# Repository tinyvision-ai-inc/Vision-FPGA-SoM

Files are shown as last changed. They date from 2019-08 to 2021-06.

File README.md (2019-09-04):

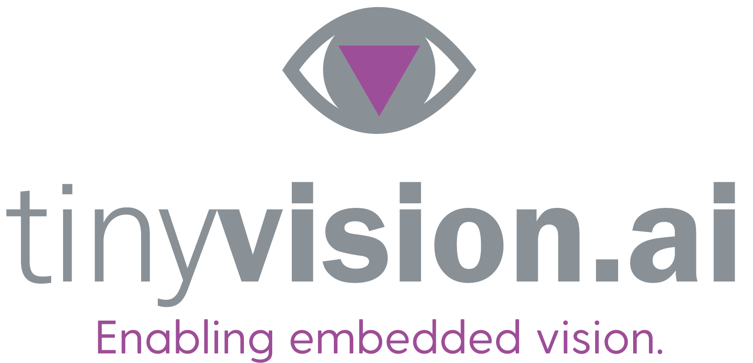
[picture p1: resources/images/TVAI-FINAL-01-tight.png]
tinyVision.ai Inc.

# Vision, Audio &amp; Motion FPGA SoM
## Low Power Sensing/processing System on Module

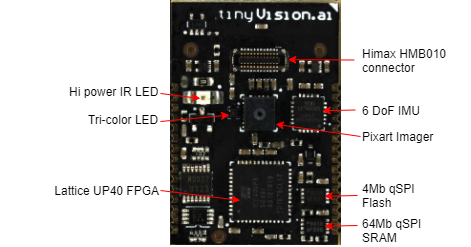
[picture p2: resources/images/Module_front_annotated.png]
Module Front


The Vision, Audio and Motion FPGA SoM enables IoT devices to see, hear and sense motion. This is a tightly integrated platform consisting of a low power image sensor, microphone and 6-DoF IMU coupled to a local computing device ([Lattice ultra low power ICE40 UltraPlus 5K FPGA](http://www.latticesemi.com/en/Products/FPGAandCPLD/iCE40UltraPlus)).

Typical applications of the SoM include image capture, trigger/capture images on motion (vision or IMU based), human face/presence detection, keyphrase detection and gestures.

The SoM is designed to be integrated into devices to enable edge computing, significantly shortening the time to market and allowing the developer to focus on their differentiation.

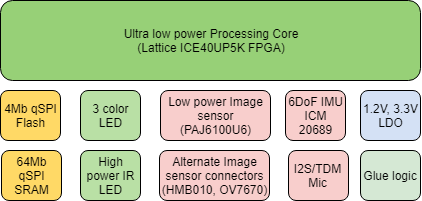
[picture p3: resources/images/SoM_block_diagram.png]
Vision Audio and Motion FPGA SoM Diagram


The module integrates the following capabilities:

- Local processing using the Lattice ICE40 Ultra Plus 5K Ultra-low-power FPGA, 5K LUT, 1Mb RAM, 8 MAC units
- Image sensor options
  - Integrated qVGA monochrome global shutter imager (Pixart PAJ6100U6)
  - Connector for color/monochrome rolling shutter imager (Himax HMB010)
  - Connector for OV7670 flex
- One MEMS I2S/TDM microphone, expandable to up to 8 microphones
- LED's
  - Tri-colour LED
  - IR LED for low light illumination with exposure synchronization
- 6 axis Gyro/accelerometer (Invensense IMU 60289)
- Memory
  - 8Mb qSPI Flash for bitstream/code storage
  - 64Mb qSPI SRAM for data
- Four GPIO, programmable IO voltage
- 4 wire SPI host interface with programmable IO voltage
- 2 power options:
  - Single 3.3V operation, can supply 1.8V and 1.2V @100mA (max) to external devices using onboard LDO
  - External 3.3V, 1.8V, 1.2V for lower power operation
- Supports the Lattice [SensAI](https://www.latticesemi.com/sensAI) toolchain using Tensorflow/Caffe/Keras for model development, quantization and mapping to the SensAI Neural Network engines.
  - Single and 8-bit neural networks
  - Models provided for face and human presence detection, gestures
  - Performance of >30 fps for inferencing at <15 mW
- Small size: 21.3mm x 31.3mm
- [Developer kit](./SoM/SoM_devkit_details.png) enables fast prototyping of complete end applications.

For more details, please see the [Datasheet](resources/som_details/Sensor_FPGA_SoM_data_sheet_2.0.pdf) and [SoM specification](SoM/README.md). A 3-D PDF rendering is available [here](resources/som_details/SoM_3D.pdf).

Modules and developer kits are available at the tinyVision.ai [store](https://tinyvision.ai/). Please contact us for questions about the module at: <sales.at.tinyvision.ai> .

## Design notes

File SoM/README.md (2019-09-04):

Module Front
<!img src="../resources/images/Module_back.jpg" alt="Module Back" width="100"/-->

# SoM Details

- [High level interconnect](../resources/images/SoM_interconnect_details.png)
- [Detailed SoM specification](./SoM_Specification.md).
- [Schematics](./Schematics)
- [Verilog examples](./RTL)
- Sensors
  - [Image sensor data](./Misc/Images)
  - [Microphone data](Misc/Audio)
  - [IMU data](./Misc/IMU)
- [STEP & DXF files](../resources/som_details/)
- [Developer kit details](../resources/images/SoM_devkit_details.png)

## Mechanical
The SoM is designed to be plugged into a connector on the host board or to be soldered down using the castellations to reduce system cost. Note that since the on-board microphone is bottom ported, this requires that the soldered down version not have a microphone which is an alternate part. Please contact us at sales.at.tinyvision.ai if this is of interest.

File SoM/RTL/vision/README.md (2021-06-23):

# High level description
The Vision directory has a basic test application that allows the user to get images from the board.

An image is captured by sending a character on the UART when the devkit is connected. The captured image is then sent back over the UART at the default baud rate of 460,800 baud. Note that this can be changed by changing the UART_PERIOD parameter in the code.

Further details can be found in the sw directory.

## Simulations
The following simulations can be run using Modelsim installed along with the Radiant toolchain. Change to the sim directory and run the following commands:
- `make TOP=<block>`: Compiles the code
- `make TOP=<block> sim`: Runs the simulation in the shell
- `make TOP=<block> sim_gui`: Runs the simulation in a GUI

Simulations are visual and not self checking, an enhancement for another day!

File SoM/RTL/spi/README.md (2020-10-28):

# SPI Slave to Wishbone Master bridge
This block forms the main core interface to the FPGA since all data enters/exits through the SPI. The design follows a simple byte oriented protocol that allows direct Wishbone read/write. Since the FPGA is a SPI slave, a side band interrupt request line is also provided and integrated into the protocol for fast interrupt service.

A SPI packet consists of the first byte containing a command followed by an optional address and either a dummy byte or write data. A dummy byte is required to do a read which takes some time in the FPGA.

The following commands are supported, roughly based on typical Flash commands:
- Read ID ( '0x90' ): A 1 byte FPGA ID will be read back immediately following this command with no dummy byte.
- Read Status ( '0x05' ): A 4 (TBD) byte Status will be read back immediately following this command with no dummy byte. A continued read of the status will show any changes in status in real time. Status words typically include an interrupt request bit.
- Write Command ( '0x01' ): This can be used to clear any sticky bits in the status register such as an interrupt request.
- Read ( '0x0B' ): A 32 bit address followed by a dummy byte then a stream of reads will cause Wishbone read's to happen every 32 bits. This scheme allows for indefinite length Read capability.
- Write ( '0x02' ): A 32 bit address and then a stream of 32 bit data wordxs follows this command. A Wishbone write goes out at every 32 bit boundary. This scheme allows for indefinite length write capability.
- Soft Reset FPGA: The FPGA can be soft reset using a pair of commands that must be sent one after the other with no other intervening commands. This prevent inadvertent FPGA resets.
  - Arm Reset ( '0x66' )
  - Fire Reset ( '0x99' )

## Interrupt Service
Interrupts are supported using a dedicated interrupt line. THis line goes active as soon as the interrupt is requested at the core interface. A STATUS read will show the source of the interrupt. Interrupts are captured on the rising edge of the core clock and can be cleared by writing the respective bit with a '1' in the command word.

## Future work
- Quad SPI support

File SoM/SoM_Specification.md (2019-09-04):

# SoM Specification

The Sensor module uses a Lattice iCE40UP5K QFN device as its core programmable device. This part is connected to and supported by various other components on the board. Please refer to the [schematic](../SoM/Schematics/SoM) of the SoM for details.

The board has an I2S microphone, Invensense IMU and an installed low power low-cost monochrome camera (PAJ6100U6) from Pixart Inc. In addition, provision is made for a Himax HM01B0 low power camera and also an OV7670 Omnivision flex connector. These options allow for various applications. An IR LED is connected to the Pixart sensor to allow for illumination of the scene with the LED synchronized to the shutter.
The FPGA is connected to 4Mb of qSPI capable NOR flash for booting as well as storage of other code. The qSPI bus is shared with a 64Mb qSPI SRAM. The SRAM can be used for buffering sensor or intermediate data such as video frames and/or audio streams. Selection between the flash and SRAM is done using dedicated active-low slave select lines.

## Electrical interface

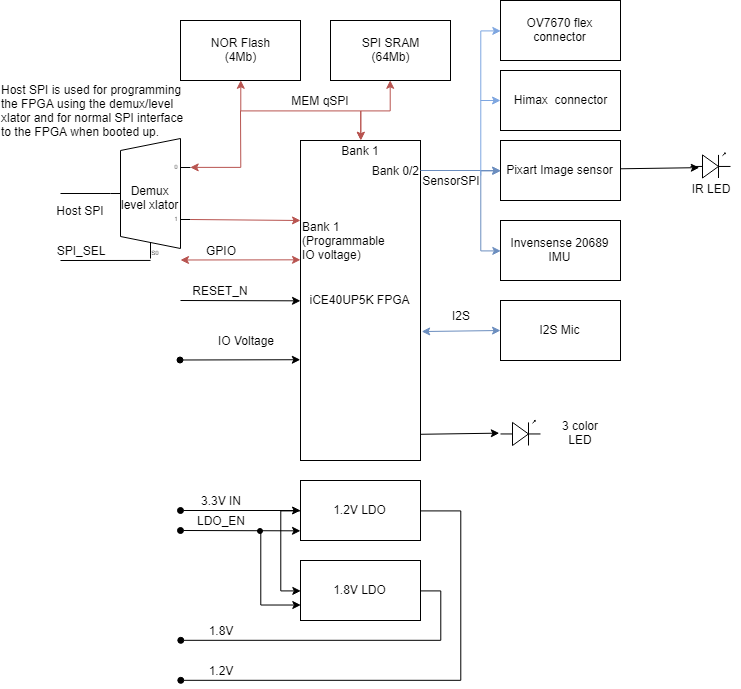
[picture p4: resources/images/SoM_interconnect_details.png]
High level interconnect


### Pinout & Signal description
All signal levels on the interface are 3.3V CMOS unless otherwise noted. A 0.5mm pitch connector is used to connect to the host board. The mate to the connector has the MPN: DF23C-30DP-0.5V(92).
The board edge castellations share the same pinout and can be used to reduce overall system cost by directly soldering the module to the host board. Note that in this configuration, the module will not have the microphone installed as it is bottom ported. The following table shows the pinout of the connector.

#### Host connector and Castellation pinout

| Pin number | Signal name | Description |
| :---: | ---: | --- |
|1, 2, 29, 30 | GND | Ground |
|3 | VDD33 | 3.3V supply |
|4 | VDD12 | 1.2V power |
|5 | LDO_EN | Enable internal LDO’s, pulled up to VDD33 with 10K resistor |
|6 | PIX_RESET_N | Assert low to reset the Pixart imager |
|7 | SCL | I2C master SCL |
|8 | NC | No connect |
|9 | SDA |I2C master SCL |
|10 |NC | No connect |
|11 |MIC_CLK |Microphone clock (Output)|
|12 |HOST_MOSI |Host master out, slave in|
|13 |MIC_DOUT |Microphone data (Input)|
|14 |HOST_SSN |Host slave select (Input)|
|15 |MIC_WS |Mic word select (Output)|
|16 |GPIO_2 |GPIO|
|17 |SENSOR_LED |External LED sync (Output)|
|18 |HOST_SCK |Host SPI clock (Input)|
|19 |SPI_SEL |Flash vs. CRAM selection, set high to program flash. (Input)|
|20 |GPIO_1 |GPIO |
|21 |PROG_FLASH |Pull low to select flash programming (Input, pulled high to 1.8V rail with 1K)|
|22 |GPIO_0 |GPIO|
|23 |DONE |FPGA done signal|
|24 |HOST_MISO |Host SPI Master In, Slave Out (Output) |
|25 |RESET_N |FPGA reset, active low, pulled to 1.8V via 1K resistor|
|26 |HOST_INTR |Interrupt pin to host, can be used as GPIO|
|27 |VDD18 | Internal 1.8V rail (Power) |
|28 |VDDIO_2 |Voltage reference for the FPGA Bank 2|

### Image subsystem
The module has an installed Pixart imager (PAJ6100) which is capable of qVGA (320x240), monochrome global shutter with excellent low light performance due to the large pixels (3um). The imager uses SPI for control and an 8-bit parallel data bus with framing signals for the data. This device requires a 6MHz (nominal) clock for its internal operations.
The Himax HMB010 imager is supported by providing a high-density connector with the right pinout. Note that the Himax imager requires multiple voltages for optimal operation which has not been provided in this version of the board.
An Omnivision OV7670 compatible flex is provided to interface with easily available higher power/resolution image sensors with a variety of lens options for specific applications.
Since the data lines for the various image sensors are shared, the Pixart imager can be held in reset to prevent it from interfering in any way with the Himax/Omnivision sensor by tying the PIX_RESET_N line low on the castellation/connector.
The Omnivision and Himax sensors use I2C as the control bus while the Pixart sensor uses SPI. The design overloads the SENSOR_SCK and SENSOR_MOSI for I2C communications. This should allow communication with the IMU to be transparent since the IMU_SSN line can be held inactive in this case.

### Memory subsystem
The module supports a 4Mb qSPI NOR flash (Winbond W25Q040) and a 64Mb qSPI SRAM (AP Memory APS1604M) connected as shown below. The flash is used to boot the FPGA as well as store any other non volatile code. The SRAM can be used to store volatile data such as images, audio buffer etc.

### IMU subsystem
The module supports a 6-axis Invensense IMU connected as shown below. The SENSOR_LED signal is used to synchronize the IMU to the image sensor for specific applications that require this functionality.

### Microphone subsystem
The module has a bottom ported I2S microphone. This microphone allows for expansion to a stereo configuration using an external I2S microphone with the SELECT line tied high. The mic is also capable of TDM operation with up to 8 mics sharing the TDM lines.

### Power
The FPGA requires 1.2V, 2.5V and 3.3V. The 2.5V is derived as a diode drop from the 3.3V supply per the Lattice reference design.
The imager requires 3.3V and 1.8V. The Himax sensor requires other voltages but appears to be capable of operating from other voltages as well.
The LDO’s can be disabled using an external pin (LDO_EN) to allow applications which already have these voltages for higher efficiency.

### FPGA programming
The FPGA can be programmed either from the onboard flash or else, through the external port allowing for applications where the external processor may want to implement this feature. 4 wires are dedicated as a SPI slave interface that the host processor can interface with. This interface is normally intended to be used to communicate with the FPGA.
On asserting the TBD signal, the 4 wire SPI FPGA programming port is MUX’ed on the same pins. Flash vs. CRAM programming is selected by the TBD signal.
The FPGA CRAM or the flash can be programmed. This requires the MISO and MOSI lines to be interchanged which is done by a mux that does double duty as a level translator.

## Mechanicals
The module measures 21.3mm x 31.3mm. A STEP file for the module to assist with mechanical integration is available [here](../resources/som_details/SoM_step.stp). A DXF file is available [here](../resources/som_details/SoM_mechanical_drawing.dxf)

## Interface API
The host interface consists of a SPI port capable of running at up to 6MHz (future FPGA code will increase this to >10MHz), an interrupt line and a couple of lines to select various FPGA programming modes.

The detailed specification is under development, requests for specific features are invited at <sales.at.tinyvision.ai>.

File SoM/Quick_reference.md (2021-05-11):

# Vision FPGA SoM Quick Reference Guide

This guide is intended to be used to:
* Figure out whether the Developer kit/SoM is functional
* Get back to the original factory shipped configuration

All devices are shipped fully tested and with a demo program. We will run the factory test program that will ensure that you verify that the devices you received work properly. If they do not pass this test, please contact: sales at tinyvision dot ai.

## Unboxing
- Carefully unpackage the SoM and developer kit. Note that the devices are ESD sensitive and appropriate care must be taken to prevent ESD damage to the devices.
- Mount the SoM on the developer kit taking care to align the connectors. There is a silkscreen guide that will help you to align the SoM. Inserting the SoM in reverse will cause damage to the device and is not covered under warranty! Please be careful!
- Connect a Micro USB cable to the dev kit and connect it to a computer.
- You should see the DS1 green LED light up indicating that the SoM is programmed. You should also see the green LED's and the small tri-color LED on the SoM cycle through 3 colors. This is the factory default setting which can be used to ensure that you have a functional device.
- Install python, OpenCV and NumPy on your machine
- Use the read_himax.py file in the repo at RTL/vision/sw to obtain an image from the image sensor. This is a 160x120 pixel grayscale image. Note that this is a limitation of the python script rather than that of the setup as the Himax sensor has a bayer color output.

> ***Note:***
>* If you do not have a developer kit, the same process can be used except that you need to provide a programmer that can program flash such as an [FTDI cable](http://www.latticesemi.com/~/media/BCA4EE8C9F8F49C4AC4A2D74737514B3.ashx) or a processor that has a SPI master port and a couple of GPIO's to spare.

## Restoring the developer kit
- Download the icestorm or Radiant toolchain
- Turn off all switches in the switch bank except for SW5 and SW8.
- Insert a jumper to enable programming
- Download the factor FPGA image from [here](SoM\RTL\vision\synth\blink_impl_1.bin)
- Program the image using icestorm/Radiant:
 ` icestorm <factory FPGA file>`
- Remove the programming jumper and push the reset button

You should now be back to the factory shipped configuration.

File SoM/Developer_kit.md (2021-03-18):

# Vision FPGA SoM Developer Kit

The SoM is supported by a developer kit. The kit is designed to enable:
* Programming/debugging the SoM
  * Ability to program one-time programmable FPGA CRAM, FPGA SRAM and Flash with bitfiles/SW images.
  * Micro USB (FT2232H) based interface
  * SPI, I2C and UART supported for SoM communication/debug
* 4 LED's on GPIO
* Programmable IO voltage capability
* Expansion to various sensors using QWIIC, PMOD and 0/1" headers
* Power measurement capability
* Easy access to all SoM interface pins on a 0.1" header
* Additional I2S microphone for stereo applications
* Ability to fully isolate the SoM for low power prototyping

## Configuration switches/jumpers
Please refer to the [SoM devkit schematics](./Schematics/Dev_kit) for details.

### Miscellaneous functions: SW1
| Switch | Name | Description |
| :---: | ---: | --- |
|1,2 | IO Voltage | The SoM can operate from either 1.8V or 3.3V IO. This switch allows selection of the IO voltage in case the devkit is being used to communicate with an external device that uses 1.8V IO. The on-board FTDI operates only at 3.3V so the switches should normally select 3.3V (SW1:1 On, SW1:2 Off) |
|3 | IR_LED Power Enable| When On, enables 3.3V to the IR LED on the SoM for night illumination. The IR LED is itself controlled by the FPGA.|
|4 | PIX_RESET_N | Normally open, can be closed to hold the on-board Pixart imager in reset. Suggest resetting the image sensor if you dont see any images coming through. The Image sensor can also be reset under SW over the SPI bus.|
|5 | LDO_EN_N | When On, the LDO's on the SoM are disabled allowing the user to source these rails from an external power source to test a high efficiency power system. The voltage pins are brought out to the prototyping area for easy access.|
|6 | Flash programming select| When On (default), selects the SoM Flash for programming|
|7 | Flash programming select| When On (default), selects the SoM Flash for programming|
|8 | CRAM Programming select | When On, selects the SoM CRAM for programming|

### IO voltage selection: SW1:[1,2]
This switch selects the IO voltage (1.8 or 3.3V) of the host interface on the SoM (GPIO and HOST_* signals). The FTDI chip operates on 3.3V hence 3.3V IO should be normally selected. This is the normally shipped configuration of the board.

### External Power: P2
External power to the board can be supplied over this port to measure power. Note that the FTDI is also powered from this port.

### PMOD: P7
A dual PMOD (6x2) is provided for convenient access to the host signals in a single location. This connector may be used to communicate with Digilent PMOD devices or used for other purposes.

### QWIIC: J1
The SoM I2C lines are translated and available on this connector to allow connectivity to the QWICC family of peripherals. Note that the INA219B power monitor as well as the SoM IMU and the FPGA are connected to this interface.

### SoM pins
All SoM pins are brought out to two dual row 0.1" headers. Pin numbers are staggered to meet the 0.05" pitch on the SoM.

## Programming details
FPGA programming can be done using either the open source [icestorm](http://www.clifford.at/icestorm/) toolchain or the Radiant programmer. The SoM allows programming of either the flash or the FPGA non-volatile RAM. Please see the table below for the switch settings to put the develop kit in various modes.

The SoM has a 4Mb WinBond W25x40CL USON8 package. Please select this in the Radiant programmer. Note that the icestorm programmer (iceprog) doesnt care what flash device is installed.

| Functionality | SW1-6	| SW1-7	| SW1-8	| Description |
| :---: | ---:  |  ---: | ---:  |--- |
| Flash | On 	| On 	| Off | FTDI connected to FPGA flash |
| CRAM/SRAM | Off  	| Off | On 	| FTDI connected to FPGA CRAM/SRAM for programming|

> ***NOTE:***
> The devkit is still in development and programming the FPGA requires that the PROGRAM jumper
> must be installed before programming. Once programmed, the PROGRAM jumper must be removed
> and the FPGA reconfigured by pressing the RESET button.

## LED's
| LED Reference | Functionality |
| :---: | --- |
| DONE | Lights up when the FPGA is programmed or the SoM is not installed. |
| INT | HOST_INTR, set high to light up the LED|
| GP_0 | GPIO 0, set high to light up the LED|
| GP_1 | GPIO 1, set high to light up the LED|
| GP_2 | GPIO 2, set high to light up the LED|

## IO voltage capability
The logic levels on the FPGA host interface (Bank 2) can be selected for compatibility with the host using this jumper. The two most commonly used logic levels (1.8V, 3.3V) can be selected.

Note that the FTDI operates at 3.3V hence, the voltage must be set to 3.3V if the FTDI is used for FPGA programming.

## Power measurement
Power is measured on the board using an INA219B chip. This I2C device can measure the 3.3V applied to the SoM and also teh current flowing intot he SoM. The data can be accessed over the I2C bus on the board either using the QWIIC connector or the FTDI as long as the SW1 settings are proerly selected.

Sample code to measure power using an Arduino is provided [here](./Boards/Artemis/Arduino/power/som_power/som_power.ino)

## Microphone
An I2S microphone is provided on the developer kit. This microphone is set to be the stereo pair for the mic on the SoM. The SoM or other I2S master can provide the I2S clock and word select. The microphones in the developer kit and SoM will work together to provide stereo data.

## Expansion connectors
The devkit provides remote microphone capability on the P5 header where power, ground and the I2S microphone signals are brought out. Note that the SoM has a microphone on this bus already and is set to be device 0. If the external microphone is used, please tie the select line low so that the microphones work together as a stereo pair.

## Miscellaneous functionality
* FPGA reset: a pushbutton is used to manually reset the FPGA and cause it to re-download.
* Prototyping area: Note that the Ground, 3.3V, 1.8V, 1.2V and IO voltages are brought out to specific pins on the proto array for users to develop their applications with. These pins are identified on the silkscreen.

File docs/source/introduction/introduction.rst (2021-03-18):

Introduction
=======

The Vision SoM is a highly capable device. We will get started with setting it up, and the "hello world" of this FPGA, getting an LED to blink!

First Steps
-----------

First things first, after ensuring your board is functioning and shows up as a USB device, the tools need to get installed. There are two paths to do:

  - APIO or icetools (For MacOS, Linux, and Windows)
  - Lattice Radiant (Linux and Windows only)

To install these tools, please go to the "Tool Installation" document!

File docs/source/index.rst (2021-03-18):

=====================
Vision FPGA SoM Documentation
=====================

tinyVision.ai Inc.
*************

Vision FPGA SoM: PCB Design Files, Designs, Documentation
------------------------------------------------------

The tinyVision.ai Vision FPGA SoM Features:

* Lattice UltraPlus ICE40UP5K FPGA with 5.3K LUTs, 1Mb SPRAM, 120Kb DPRAM, 8 Multipliers
* Open source schematic and layout using Altium design tools
* Integrated into the open source `APIO toolchain <https://github.com/FPGAwars/apio>`_

Useful links:

* `osresearch <https://github.com/osresearch/up5k>`_: large collection of very useful code and a good overview.
* `UPduino FPGA tutorial using APIO <https://blog.idorobots.org/entries/upduino-fpga-tutorial.html>`_
* `A very detailed blog on implementing a RISCV in the FPGA <https://pingu98.wordpress.com/2019/04/08/>`_

.. toctree::
   :hidden:

   self
   
.. toctree::
   :maxdepth: 2
   :caption: Introduction
   :hidden:

   introduction/introduction

.. toctree::
   :maxdepth: 2
   :caption: Getting Started
   :hidden:

   getting_started/tool_installation
   getting_started/first_steps

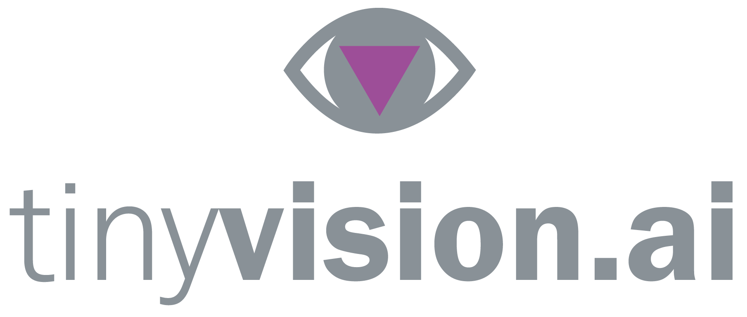
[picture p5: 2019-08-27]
resources/images/TVAI-FINAL-02-tight.png

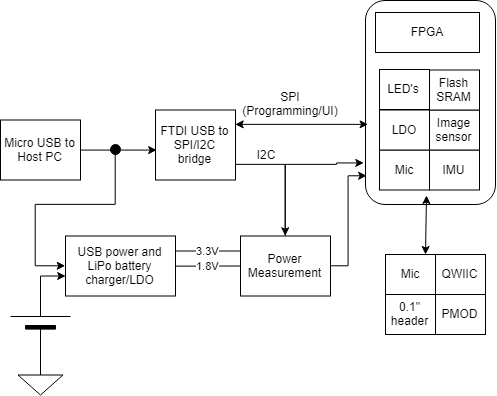
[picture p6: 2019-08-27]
resources/images/SoM_devkit_details.png

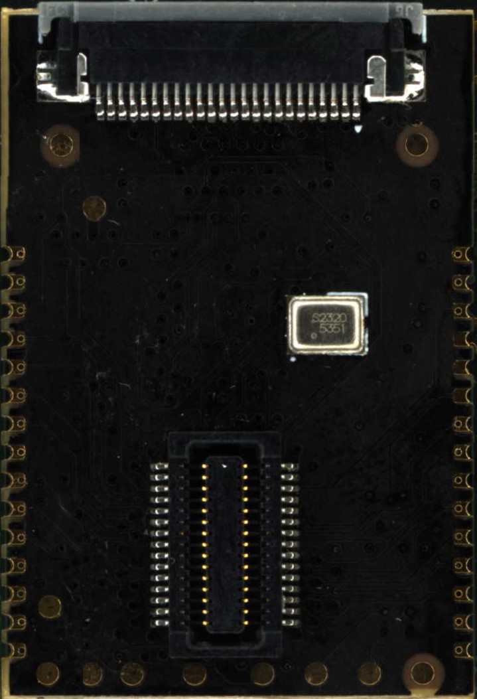
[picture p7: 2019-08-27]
resources/images/Module_back.jpg

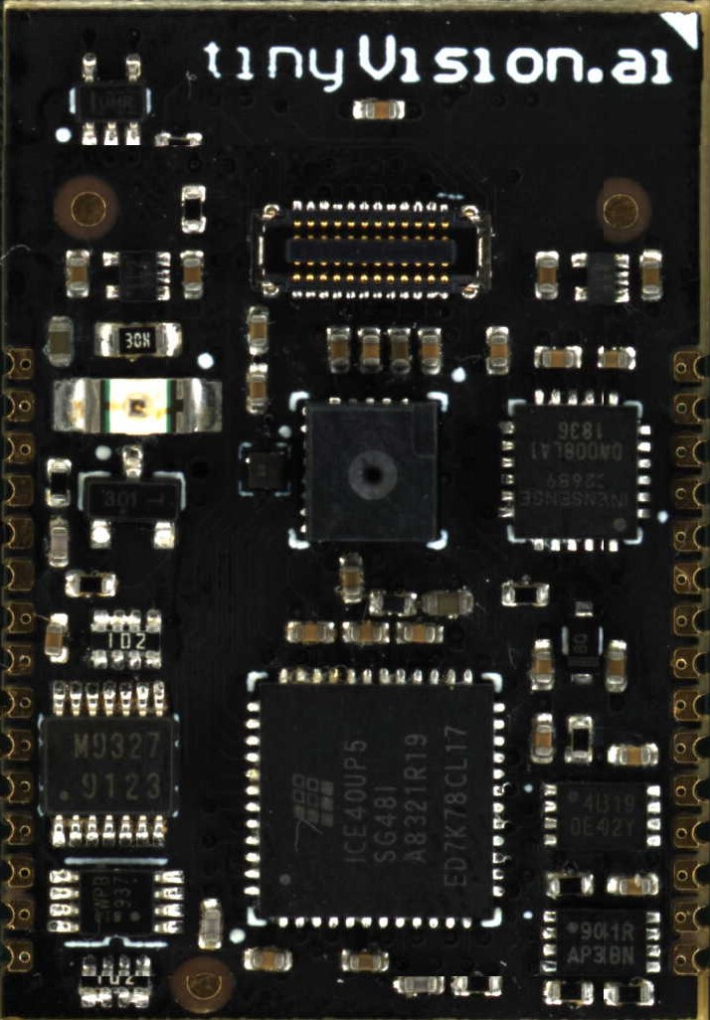
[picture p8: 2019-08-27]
resources/images/Module_front.jpg

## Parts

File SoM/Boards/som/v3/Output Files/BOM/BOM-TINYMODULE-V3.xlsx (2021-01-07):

Comment | Description | Designator | Footprint | LibRef | Quantity | Supplier Part Number | Manufacturer | Manufacturer Part Number | Supplier
4.7uF | CAP CER 4.7UF 6.3V X5R 0402 | C1, C2, C3, C4, C5, C15, C21, C33 | CAPC100X50X60L25N | Cap_1uF_X5R_10%_6V3_0402, CAP NP | 8 | 490-18211-1-ND | Murata Electronics | GRM155R60J475ME87J | Digi-Key
0.1uF | CAP CER 0.1UF 10V X5R 0402 | C10, C11, C12, C13, C16, C17, C18, C19, C20, C22, C23, C24, C26, C27, C29, C30, C32 | CAPC100X50X60L25N | Cap_100nF_X7R_10%_0402 | 17 | 490-6297-1-ND | Murata Electronics | GRM155R61A104KA01J | Digi-Key
470pF | CAP CER 470PF 50V X7R 0402 | C25, C28 | CAPC100X50X60L25N | CAP, Cap_100nF_X7R_10%_0402 | 2 | 490-1300-1-ND | Murata Electronics | GRM155R71H471KA01D | Digi-Key
DNI | CAP CER 4.7UF 10V X5R 0402, CAP CER 0.1UF 6.3V X5R 0402 | C6, C7, C8, C9, C14, C31 | CAPC100X50X60L25N | Cap_1uF_X5R_10%_6V3_0402, Cap_100nF_X7R_10%_0402 | 6 |  |  |  |  | DNI
VSMY12850 | EMITTER IR 850NM 70MA 3.20MM SMD | D1 | vsmy12850 | LED | 1 | VSMY12850CT-ND | OSRAM Opto Semiconductors Inc. | VSMY12850 | Digi-Key
UHD1110-FKA-CL1A13R3Q1BBQFMF3 | HB, SMD, RGB | D2 | UHD1110-FKA | UHD1110-FKA-CL1A13R3Q1BBQFMF3 | 1 | UHD1110-FKA-CL1A13R3Q1BBQFMF3CT-ND | Cree Inc. | UHD1110-FKA-CL1A13R3Q1BBQFMF3 | Digi-Key
1N4148WT-7 | DIODE GEN PURP 80V 125MA SOD523 | D3 | SOD523F | DIODE | 1 | 1N4148WTDICT-ND | Diodes Incorporated | 1N4148WT-7 | Digi-Key
FCM | Fiducial marker | FD1, FD2, FD3, FD4, FD5, FD6 | FID100X200N | FCM | 6 |  |  |  |  | DNI
52437-2491 | Connector | J1 | 524372491 | 52437-2491 | 1 |  |  | 52437-2491
CONN_GENERIC_15 |  | LEFT1, RIGHT1 | CONN_GENERIC_1.27mm_15cont | CONN_GENERIC_15 | 2 |  |  |  |  | DNI
SPH0645LM4H-B | CRAWFORD MIC DGT I2S BOTTOM PORT | MK1 | Knowles_SPH0645LM4H-B_0 | SPH0645LM4H-B | 1 | 423-1405-1-ND | Knowles | SPH0645LM4H-B | Digi-Key
503772-2420 | CONN RCPT 24POS SMD GOLD | P1 | 503772-2410 | Header 12X2A | 1 | WM25543CT-ND | Molex | 5037722420 | Digi-Key
DF23C-30DS-0.5V(51) | Header, 15-Pin, Dual row | P2 | DF23C-30DS-0.5V | Header 15X2 | 1 | 798-DF23C30DS05V51 | Hirose | DF23C-30DS-0.5V(51) | Mouser
FDV301N | MOSFET N-CH 25V 220MA SOT-23 | Q1 | FAIR-SOT23-3_V | CMP-2000-04935-1 | 1 | FDV301NCT-ND | ON Semiconductor | FDV301N | Digi-Key
10k | RES 10K OHM 1/16W 5% 0402 | R1, R4, R6, R8, R9, R10 | RESC100X50X40L25N | Res_10K_1%_0402 | 6 | RMCF0402JT10K0CT-ND | STACKPOLE | RMCF0402JT10K0 | Digi-Key
20 | RES 20 OHM 5% 1/16W 0402 | R2 | RESC1608X55N | Res_10K_1%_0402 | 1 | RMCF0402JT20R0CT-ND | STACKPOLE | RMCF0402JT20R0 | Digi-Key
0 | RES SMD 0 OHM JUMPER 1/16W 0402 | R5 | RESC100X50X40L25N | Res_10K_1%_0402 | 1 | 311-0.0JRCT-ND | Yageo | RC0402JR-070RL | Digi-Key
100 | RES 100 OHM 5% 1/16W 0402 | R7 | RESC100X50X40L25N | Res_100_1%_0402 | 1 | RMCF0402JT100RCT-ND | STACKPOLE | RMCF0402JT100R | Digi-Key
4.7k | RES SMD 4.7K OHM 5% 1/16W 0402 | R13, R14 | RESC100X50X40L25N | Res_10K_1%_0402 | 2 | 311-4.7KJRCT-ND | Yageo | RC0402JR-074K7L | Digi-Key
10K | RES ARRAY 4 RES 10K OHM 0804 | RN1, RN2, RN3 | RESCAXS50P100X200X45-8NA | EXB28V | 3 | 741C083103JPCT-ND | CTS Resistor Products | 741C083103JP | Digi-Key
DNI | RES 10K OHM 1/16W 5% 0402 | R3 | RESC100X50X40L25N | Res_10K_1%_0402 | 1 |  |  |  |  | DNI
TEST POINT |  | TP1, TP2, TP3, TP4, TP5, TP6, TP7, TP8, TP9 | TP-R20 | TEST POINT | 9 |  |  |  |  | DNI
ICM-20689 | IMU ACCEL/GYRO/TEMP I2C/SPI QFN | U4 | QFN50P400X400X95-25N | MPU-6500 | 1 | 1428-1059-1-ND | TDK InvenSense | ICM-20689 | Digi-Key
ICE40UP5K-SG48I | IC FPGA 39 I/O 48QFN | U5 | SLAB-QFN48-7X7-MD | ICE40UP5K-SG48I | 1 | 220-2212-1-ND | Lattice Semiconductor | ICE40UP5K-SG48I | Digi-Key
TC7MPB9327FK(EL) | X34 DUAL-SUPPLY LEVEL SHIFT SPDT | U6 | VSSOP14-P-0030-0.50 | TC7MPB9327FK | 1 | TC7MPB9327FK(EL)CT-ND | Toshiba Semiconductor and Storage | TC7MPB9327FK(EL) | Digi-Key
SST26WF080BT-104I/NP | IC FLASH 8M SPI 104MHZ 8USON | U7 | SON50P300X200X60-9N | IS25WQ040-JNLE | 1 | SST26WF080BT-104I/NPCT-ND | Microchip Technology | SST26WF080BT-104I/NP | Digi-Key
TC7WPB9307FK,LF(CT | X34 GENERAL-PURPOSE BUS SWITCH L | U8 | SSOP8-P-0.50A | TC7WPB9307FK | 1 | TC7WPB9307FKLF(CTCT-ND | Toshiba Semiconductor and Storage | TC7WPB9307FK,LF(CT | Digi-Key
SN74AUC1G125DCKR | IC BUF NON-INVERT 2.7 V SC70-5 | U10 | DCK0005A_L | TI-SN74AXXXX1X125-5 | 1 | 296-12658-1-ND | Texas Instruments | SN74AUC1G125DCKR | Digi-Key
APS1604M-SQR-ZR | qSPI SRAM | U9 | SON50P300X200X60-9N | IS25WQ040-JNLE | 1 |  | APMEMORY
TCR2LE28ESV |  | U11 | SOT-553 | TCR2LE12ESV | 1 |  | Toshiba
TCR2LE18ESV |  | U1 | SOT-553 | TCR2LE12ESV | 1 |  | Toshiba
TCR2LE12ESV |  | U2 | SOT-553 | TCR2LE12ESV | 1 |  | Toshiba
PAJ6100U6 | Camera Module | U3 | lga26 | PAJ6100U6_DS | 1 |  | PixArt Imaging Inc | PAJ6100U6

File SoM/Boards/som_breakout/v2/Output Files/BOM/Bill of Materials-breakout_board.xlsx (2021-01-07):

Comment | Description | Designator | Footprint | Quantity | Digi-Key Part Number | Manufacturer | Manufacturer Part Number | Supplier 1
4.7uF | CAP CER 4.7UF 6.3V 0402 | C1, C2, C3, C4 | CAPC1005X61USR | 4 | 399-5499-1-ND | KEMET | C0402C475M7PACTU | Digi-Key
0.1uF | CAP CER 0.1UF 6.3V 0402 | C5, C6 | CAPC1005X61USR | 2 | 399-1043-1-ND | KEMET | C0402C104Z4VAC7867 | Digi-Key
GREEN | Avago HSMG-C170 | CHG | LED_0805 | 1 | 516-1434-1-ND | Avago Technologies US Inc. | HSMG-C170 | Digi-Key
DONE | Avago HSMG-C170 | CHG1 | LED_0805 | 1 | 516-1434-1-ND | Avago Technologies US Inc. | HSMG-C170 | Digi-Key
BAT54C-E3-08 | DIODE ARRAY SCHOTTKY 30V SOT23 | D1 | SOT-23 | 1 | BAT54C-E3-08CT-ND | Rectron | BAT54C-E3-08 | Digi-Key
DF23C-30DP-0.5V(92) | CONN PLUG 30POS SMD GOLD | J1 | SOM-SMD | 1 | H11880CT-ND | Hirose Electric Co Ltd | DF23C-30DP-0.5V(92) | Digi-Key
Li Ion | CONN HEADER SMD R/A 2POS 2MM | J2 | JST_S2B-PH-SM4-TB(LF)(SN) | 1 | 455-1749-1-ND | JST Sales | S2B-PH-SM4-TB(LF)(SN) | Digi-Key
 | CONN HEADER SMD R/A 4POS 1MM | J3 | 1X04_1MM_RA | 1 | 455-1804-1-ND | JST Sales America Inc. | SM04B-SRSS-TB(LF)(SN) | Digi-Key
MOUNTING HOLE |  | MNT1, MNT2, MNT3, MNT4 | MNT620-275N | 4 |  |  | DNP
Header 4 | Header, 4-Pin | P1 | HDR1X4 | 1
0475890001 | CONN RCPT MICRO USB AB 5P SMD RA | P3 | *MOLEX_0475890001 | 1 | WM17143CT-ND | Molex | 0475890001 | Digi-Key
Header 12 | Header, 12-Pin | P4 | HDR1X12 | 1 |  |  | DNP
Header 16 | Header, 16-Pin | P5 | HDR1X16 | 1 |  |  | DNP
1K | RESISTOR 1K OHM 1% 0.0625W 0402 | R1, R3 | RESC1005X40USR | 2 | 311-1.00KLRCT-ND | Yageo | RC0402FR-071KL | Digi-Key
10K | RES SMD 10K OHM 1% 1/16W 0402 | R2 | RESC1005X40USR | 1 | 311-10.0KLRCT-ND | Yageo | RC0402FR-0710KL | Digi-Key
47K | RES ARRAY 4 RES 47K OHM 0804 | RN1 | RESCAXS50P100X200X45-8NA | 1 | Y10473CT-ND | Panasonic | EXB-N8V473JX | Digi-Key
PTS820 J25K SMTR LFS | SWITCH TACTILE SPST-NO 0.05A 12V | SW1 | PTS820J25MSMTRLFS | 1 | CKN10897CT-ND | C&K | PTS820 J25K SMTR LFS | Digi-Key
TEST POINT |  | TP1, TP2 | TP 1mm | 2 |  |  | DNP
SPX3819M5-L-3-3/TR | IC REG LINEAR 3.3V 500MA SOT23-5 | U1 | SOT-23-5 | 1 | 1016-1873-2-ND | MaxLinear, Inc. | SPX3819M5-L-3-3/TR | Digi-Key
MCP73831T-2ACI/OT | IC CONTROLLR LI-ION 4.2V SOT23-5 | U2 | SOT-23-5 | 1 | MCP73831T-2ACI/OTTR-ND | Microchip Technology | MCP73831T-2ACI/OT | Digi-Key
TC7WPB9307FK | X34 GENERAL-PURPOSE BUS SWITCH L | U3 | 8-VFSOP | 1 | TC7WPB9307FKLF(CTTR-ND | Toshiba Semiconductor and Storage | TC7WPB9307FK,LF(CT | Digi-Key
FCM |  | Z_FDM1, Z_FDM2, Z_FDM3 | FID100X250N | 3 |  |  | DNP

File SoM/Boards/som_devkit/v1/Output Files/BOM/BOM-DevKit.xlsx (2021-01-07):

Comment | Description | Designator | Footprint | Quantity | Mfg | MPN | Supplier PN
4.7uF | CAP CER 4.7UF 6.3V 0402 | C1, C11, C21, C22, C23, C24, C30, C31, C37 | CAPC1005X60N | 9 | KEMET | C0402C475M7PACTU | 399-5499-1-ND
0.1uF | CAP CER 0.1UF 16V Y5V 0402 | C2, C3, C4, C5, C6, C7, C8, C9, C10, C12, C13, C15, C16, C18, C19, C20, C25, C26, C27, C28, C29, C32, C33, C34, C35, C36, C38, C39 | CAPC1005X60N | 28 | KEMET | C0402C104Z4VAC7867 | 399-1043-1-ND
DNI | CAP CER 0.1UF 6.3V 0402 | C14 | CAPC1005X60N | 1 |  | DNP
470pF | CAP CER 470PF 50V 5% NP0 0402 | C17 | CAPC1005X60N | 1 | Murata Electronics | GRM1555C1H471JA01D | 490-1297-1-ND
GREEN | LED GREEN DIFFUSED CHIP SMD | DONE, GP_0, GP_1, GP_2, INT | LED2012N | 5 | Broadcom Limited | HSMG-C170 | 516-1434-1-ND
BLM18HE152SN1D | FERRITE BEAD 1.5 KOHM 0603 1LN | FB1, FB2 | MURA-BLM18-RF-H4-CHIP-2_V | 2 | Murata | BLM18HE152SN1D | 490-5216-1-ND
SM04B-SRSS-TB(LF)(SN) | CONN HEADER SMD R/A 4POS 1MM | J1 | 1X04_1MM_RA | 1 | JST Sales America Inc. | SM04B-SRSS-TB(LF)(SN) | 455-1804-1-ND
CONN_GENERIC_16 |  | LEFT1, LEFT2, LEFT3, LEFT4, LEFT5, LEFT6, LEFT7, RIGHT1 | HDR2x8 | 8 |  | DNP
SPH0645LM4H-B | Mic Mems Digital I2s Omni -26db | MK1 | Knowles_SPH0645LM4H-B_0 | 1 | Knowles | SPH0645LM4H-B | 423-1405-1-ND
MOUNTING HOLE |  | MNT1, MNT2, MNT3, MNT4 | MNT620-275N | 4 |  | DNP
0475890001 | CONN RCPT MICRO USB AB 5P SMD RA | P1 | *MOLEX_0475890001 | 1 | Molex | 0475890001 | WM17143CT-ND
External Power | Header, 2-Pin | P2 | HDR1X2 | 1 |  | DNP
DF23C-30DS-0.5V(51) | Header, 15-Pin, Dual row | P3 | DF23C-30DS-0.5V | 1 | Hirose Electric Co Ltd | DF23C-30DS-0.5V(51) | H11879CT-ND
Mic connector | Header, 5-Pin | P5 | HDR1X5 | 1 | Würth Elektronik | 61300511121 | 732-5318-ND
Header 6X2H | Header, 6-Pin, Dual row, Right Angle | P7 | HDR2X6H | 1 | Amphenol ICC (FCI) | 67997-212HLF | 609-3237-ND
1K | RESISTOR 1k OHM 1% 0.0625W 0402 | R1, R2, R16, R17, R18, R19 | RESC1005X40N | 6 | Yageo | RC0402FR-071KL | 311-1.00KLRCT-ND
0 | RES SMD 0 OHM JUMPER 1/10W 0603 | R3, R4, R8, R9 | RESC1005X40N | 4 | Yageo | RC0603FR-070RL | 311-0.0HRTR-ND
10K | RES 10K OHM 5% 1/16W 0402, RES SMD 10K OHM 1% 1/16W 0402 | R5, R6, R11, R12, R13, R14, R15, R24, R27, R28, R29 | RESC1005X40N | 11 | Yageo | RC0402FR-0710KL | 311-10.0KLRCT-ND
1 | RES 1 OHM 1/16W 5% 0402 | R7 | RESC1005X40N | 1 | Yageo | RC0402JR-071RL | 311-1.0JRCT-ND
27 | RES 27 OHM 5% 1/16W 0402 | R10, R20, R21, R23, R25, R26 | RESC1005X40N | 6 | Yageo | RC0402JR-0727RL | 311-27JRCT-ND
12K | RESISTOR 12K OHM 1% 0.0625W 0402 | R22 | RESC1005X40N | 1 | Yageo | RC0402FR-0712KL | 311-12.0KLRCT-ND
Module | Module | SOM | SOM-SMD | 1 | Hirose | DF23C-30DP-0.5V(92) | H11880CT-ND
219-8LPST | Switch, SPST, Surface Mount DIP, 8-way, 16-Pin DIP | SW1 | CTS-219-8LPST_V | 1 | CTS Electrocomponents | 219-8LPST | CT2198LPST-ND
PTS820 J25K SMTR LFS | SWITCH TACTILE SPST-NO 0.05A 12V | SW2 | PTS820J25MSMTRLFS | 1 | C&K | PTS820 J25K SMTR LFS | CKN10897CT-ND
AP2120N-3.3TRG1 | IC REG LINEAR 3.3V 150MA SOT23 | U1 | *SOT91P240X110-3N | 1 | Diodes Inc. | AP2120N-3.3TRG1 | AP2120N-3.3TRG1DICT-ND
FT2232HL-Reel | IC USB HS DUAL UART/FIFO 64-LQFP | U2 | LQFP-64 | 1 | FTDI | FT2232HL-Reel | 768-1024-1-ND
93LC56BT-I/OT | IC EEPROM 2K SPI 2MHZ SOT23-6 | U3 | SOT-23-OT6_L | 1 | Microchip Technology | 93LC56BT-I/OT | 93LC56BT-I/OTCT-ND
ESDR0502NMUTAG | TVS DIODE 5.5V 6UDFN | U4 | ONSC-UDFN-6-517AA-01_V | 1 | ON Semiconductor | ESDR0502NMUTAG | ESDR0502NMUTAGOSCT-ND
24AA01T-I_OT | IC EEPROM 1K I2C 400KHZ SOT23-5 | U5 | SOT23-5 | 1 | Microchip Technology | 24AA01T-I/OT | 24AA01T-I/OTCT-ND
Raspberry_Pi_Zero_W__v1.3_ | CONN HDR 40POS 0.1 TIN SMD | U6 | RPI0w1.3 | 1 | Sullins Connector Solutions | NPTC202KFMS-RC | S5690-ND
INA219BIDCNR | IC CURRENT MONITOR 1% SOT23-8 | U8 | DCN0008A_M | 1 | Texas Instruments | INA219AIDCNR | 296-23770-1-ND
TC7WPB9307FK | Dual bidirectional level translator | U9 | SSOP8-P-0.50A | 1 | Toshiba Semiconductor and Storage | TC7WPB9307FK,LF(CT | TC7WPB9307FKLF(CTCT-ND
12MHz | MEMS OSC XO 12.0000MHZ H/LV-CMOS | Y1 | SOT23-5 | 1 | SiTIME | SIT2001BI-S2-33E-12.000000G | 1473-SIT2001BI-S2-33E-12.000000G-ND
FCM |  | Z_FDM1, Z_FDM2, Z_FDM3, Z_FDM4, Z_FDM5, Z_FDM6 | FID100X250N | 6 |  | DNP

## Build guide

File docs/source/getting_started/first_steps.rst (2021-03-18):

First Steps
====

1. When you receive your Vision SoM, make sure it works properly before you proceed further! A simple way to do this is to plug it into a standard micro USB cable attached to a standard USB power supply such as a computer or a phone charger. 
  - You should see the 3 color LED cycle through Red-Green-Blue.
  - If you have the developer kit, the SoM will cycle all LED's on the board in a binary incrementing pattern. 
  - Also, if you are on a computer, you should see a new USB device called the "Vision FPGA SoM" show up in your list of USB devices. 
  - The board shows up as a pair of serial ports (COMxx on windows and /dev/ttyUSB0, /dev/ttyUSB1 on Linux and Mac). If this doesnt happen, please copy the SoM/Setup/udev-rules/* to the /etc/udev/rules.d location as root.
2. Download the toolchain of choice: Lattice Radiant and/or icestorm/apio.
3. Download the git repository for the Vision SoM and go the RTL/blink_led directory.
4. Test your toolchain installation:
  - apio/icestorm toolchain:
    - Type in "make design=blink_led" and this should create a bin file to be uploaded to the SoM. 
    - For Windows, you will need to install Zadig and go through the process of switching the SoM devkit to the libusbk driver so that iceprog can see this. An alternative is to install the iceprog tool for windows and use that for programming instead of the icestorm version, some instructions are on [this forum](https://forum.1bitsquared.com/t/official-win10-instructions-missing/73).
    - Program the SoM and ensure the DONE LED lights up and the 3 color LED starts cycling through its sequence.
5. Fiddle with the code!

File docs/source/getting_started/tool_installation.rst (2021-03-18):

Tool Installation
=================

The SoM can use an FPGA image generated from either the open source icestorm/apio toolchain or the Lattice Radiant tools.

icestorm Tool Installation
----

You can follow the instructions to install the icestorm toolchain from various links on the web. Some are listed below for reference:
- https://github.com/FPGAwars/toolchain-icestorm/wiki

APIO installation
-----------------

APIO is a powerful open source ecosystem for FPGAs. To install it, use pip, and go:
``pip install apio``

As the UPduino is fairly new, however, this release does not include the software to include the UPduino 3. Thus, you will need to manually configure it. Dowload the newest commit of APIO from here: https://github.com/FPGAwars/apio

To find out where pip installed apio on your system, go:
``pip show apio``

Go there, open the apio folder, and replace its contents (but not the folder itself) with the contents of the "apio" folder in the downloaded commit of the apio directory. **Note:** If you would like to be able to easily update it, as apio is frequently updated due to its open sourse nature, you can use Git.

Note, this process of replacement is limited to pip. If you use a different package manager, refer to where it stores its downloaded and installed packages.

Lattice Radiant Installation
----
You can follow instructions from the Lattice website to install Radiant. Note that this tool only support Linux and Windows.

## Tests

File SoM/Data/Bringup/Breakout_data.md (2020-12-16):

# Vision SoM Feather Breakout bringup

## Voltages
| Node 	| Expected| Measured |
| :---: | ---: 			| --- |
| VUSB 	| 5V+/-10% 		| 5.078V|
| VBATT (No battery)| 3.7V-4.2V 		| 4.289V|
| VBATT (Only battery) | 3.7V-4.2V 		| 4.097V|
| VBATT (USB+Battery)| 3.7V-4.2V 		| 4.134V|
| 3.3V 	| 3.3V+/- 10% 	| 3.297V|
| 1.8V 	| 1.8V+/- 10% 	| 1.800V|
| 1.2V 	| 1.2V+/- 10% 	| 1.203V|

## Miscellaneous functions
- Charge LED comes on when batery is plugged in along with USB. Battery voltage seen to rise slowly. Charge LED doesnt come on when there is no battery.
- Pushing the reset switch resets the FPGA
- DONE LED comes on when the FPGA is successfully programmed

## Feather
Connect to an ESP32 Feather. Check for whether power and charge functionality work with USB and battery. Also check if the reset button resets the Feather.
Result: USB on either Feather or the SoM breakout powers the stack. Battery charges when USB is in either ESP32 or SoM feather. Reset button on the SoM feather resets the ESP32.

## Untested
- QWIIC connection, I2C

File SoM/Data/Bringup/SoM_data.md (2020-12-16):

# Vision SoM data

Setup: SoM mounted on a developer kit board. Yosys environment.

## Voltages
| Node 	| Expected| Measured |
| :---: | ---: 			| --- |
| 3.3V 	| 3.3V+/- 10% 	| 3.301V|
| 1.8V 	| 1.8V+/- 10% 	| 1.801V|
| 1.2V 	| 1.2V+/- 10% 	| 1.203V|

## FPGA Programming
1. CRAM Programming: SW1, SW8: ON, all others off. Command line: "iceprog -S <design.bin>"
2. Flash Programming: SW1, SW6, SW7: ON, all others off. Command line: "iceprog <design.bin>"

Passed both flash and SRAM programming. Flash ID reads back as 0xEF6013.

## LED's
Procedure: Turn on each of the LED's individually.

| LED 	| Status|
| :---: | ---:|
| RED 	| Pass|
| GREEN 	| Pass|
| BLUE 	| Pass|
| IR_LED | Fail, IR LED's are on backwards! Passes on older SoM's |

## Microphones
Setup: Apply 3MHz clock and 3MHz/64 framing (Word Select) to the microphones.
Result: See data coming in on both high and low periods. Test with the breakout board as well where the mic only outputs during the high period of the word select as expected.

## I2C
Scan the I2C bus and report back any devices.
Result: Scan finds 2 devices on the breakout board: 0x69 (IMU) and 0x24 (HM01B0). On scanning the developer kit, we get an additional device at 0x40 (INA219B).

## Power Measurement
Load the INA219 code into the ESP32 and get shunt voltage measurements. Voltage across the 1 Ohm current sense resistor looks reasonable and comparable to whats measured with a DMM (13mV).

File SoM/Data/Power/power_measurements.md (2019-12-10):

# Power measurements on the SoM v3 with devkit
Power measured by the INA219 sensor on the devkit.

## Data
| Condition | Power | Description |
| :---: | ---: | --- |
| No SoM | 0mW | No SoM inserted|
| Blank Flash | 14mW | FPGA not programmed |
| FPGA reset | 10mW | FPGA held in reset using push button |
| Zero design | 9.5mW | Minimal design with no blinking LED's |
| Red LED on | 59.22mW |  Zero design with red LED on |
| Green LED on | 39.2mW |  Zero design with Green LED on |
| Blue LED on | 37.1 mW |  Zero design with Blue LED on |
| All LED's on | 108mW | All LED's on full blast |
| IR LED on | 106.4mW | IR LED on full blast, note that the Pixart imager must be kept in reset for this case since the drive is supposed to come from it! Without pre-configuring the Pixart imager first, we end up backdriving the device leading to higher power consumption. |
| GPIO LED | 57.8mW | Single GPIO LED turned on|
| 48MHz osc  | 11-14mW | Added 48MHz osc |
| PLL@20MHz  |  | Added PLL with a 20MHz oscillator output |

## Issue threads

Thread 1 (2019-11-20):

verilog code samples

peepo, 2019-11-20:
Venkat,

I have one of your beautiful boards:

Please could you publish the code samples for the other projects you list?

image sensor
IMU
Microphone

it is difficult to use without these!

xx

SensAI less so as Lattice provides some examples.

vr2045, 2019-11-21:
Hi JC,

Could you please clarify which board you have? The Himax board was built by tinyVision but supported currently by Lattice. This has 2 mics but no IMU.

The code for the SoM is in development but could conceivably be used in the Himax board...

If you'd like, I can send you a discord channel invite and we can chat in real time instead.

lloo099, 2020-06-26:
Hi Venkat,

Could you please share the testbench of your MIPI model?

vr2045, 2020-10-28:
Please see the RTL/vision directory. No MIPI is used.

Closed 2020-10-28.

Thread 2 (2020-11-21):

where is PAJ6100U6 datasheet or sample code?

nanfang2000, 2020-11-21:
where is PAJ6100U6 datasheet or sample code?
how to read the camera data?
Thank you!

vr2045, 2021-03-10:
Unfortunately, I cannot share the PAJ datasheet which is under NDA.
Sample FPGA code is provided for the Himax sensor that allows obtaining an image.

Himax is the shipped configuration though the board supports either sensor. The Pixart sensor is not installed on the crowdfunded SoM's.

Closed 2021-03-10.

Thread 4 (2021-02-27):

Schematic - FPGA Pins 35 and 43 Appear To Be Swapped - Please See Attached Image

whathisface, 2021-02-27:
Hello,

The signals:

PX_CLK - Pin 35 of FGPA and
IMAGER_SSN - Pin 43 of the FPGA appear to be swapped in the TINYMODULE-V3 schematic.

Please see the attached:

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

Regards,
whathisface

vr2045, 2021-03-10:
Thank you for looking into this! The schematic you're using is from before the crowdfunding. This was updated by moving the pixel clock to pin 43 as shown in the PDC file which is current.

The reason for the move is that you're not allowed to make pin 35 and input while placing the PLL. By moving the pixel clock to a different pin, the PLL can be placed.

I will update the schematic online so it reflects the latest design...

Closed 2021-03-10.

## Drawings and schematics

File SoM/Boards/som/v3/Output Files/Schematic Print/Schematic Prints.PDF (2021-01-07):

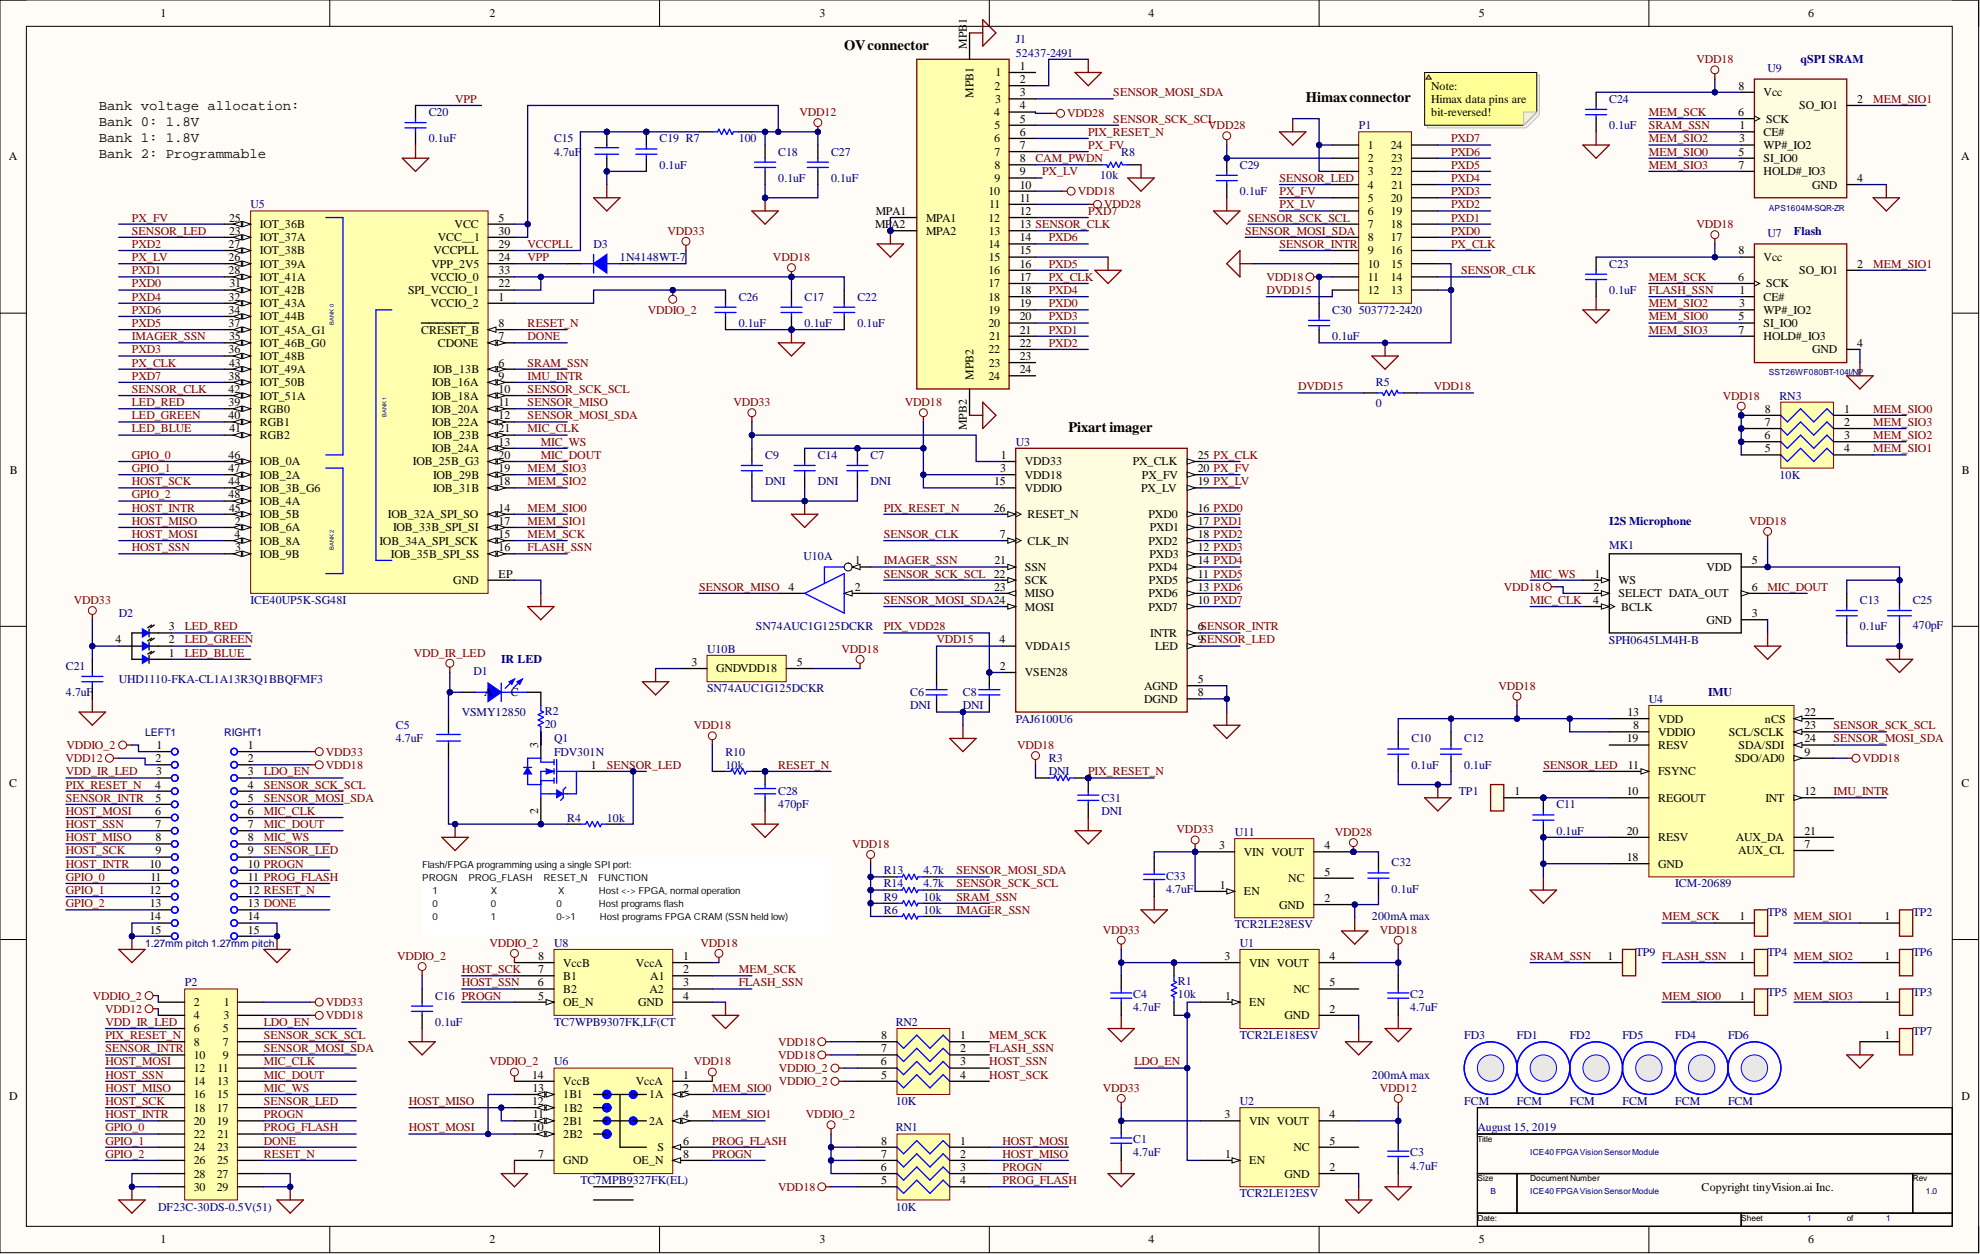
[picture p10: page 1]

Note:
Himax data pins are
bit-reversed!

Flash/FPGA programming using a single SPI port:
PROGN PROG_FLASH RESET_N FUNCTION

PROGN | 7

Copyright tinyVision.ai Inc.

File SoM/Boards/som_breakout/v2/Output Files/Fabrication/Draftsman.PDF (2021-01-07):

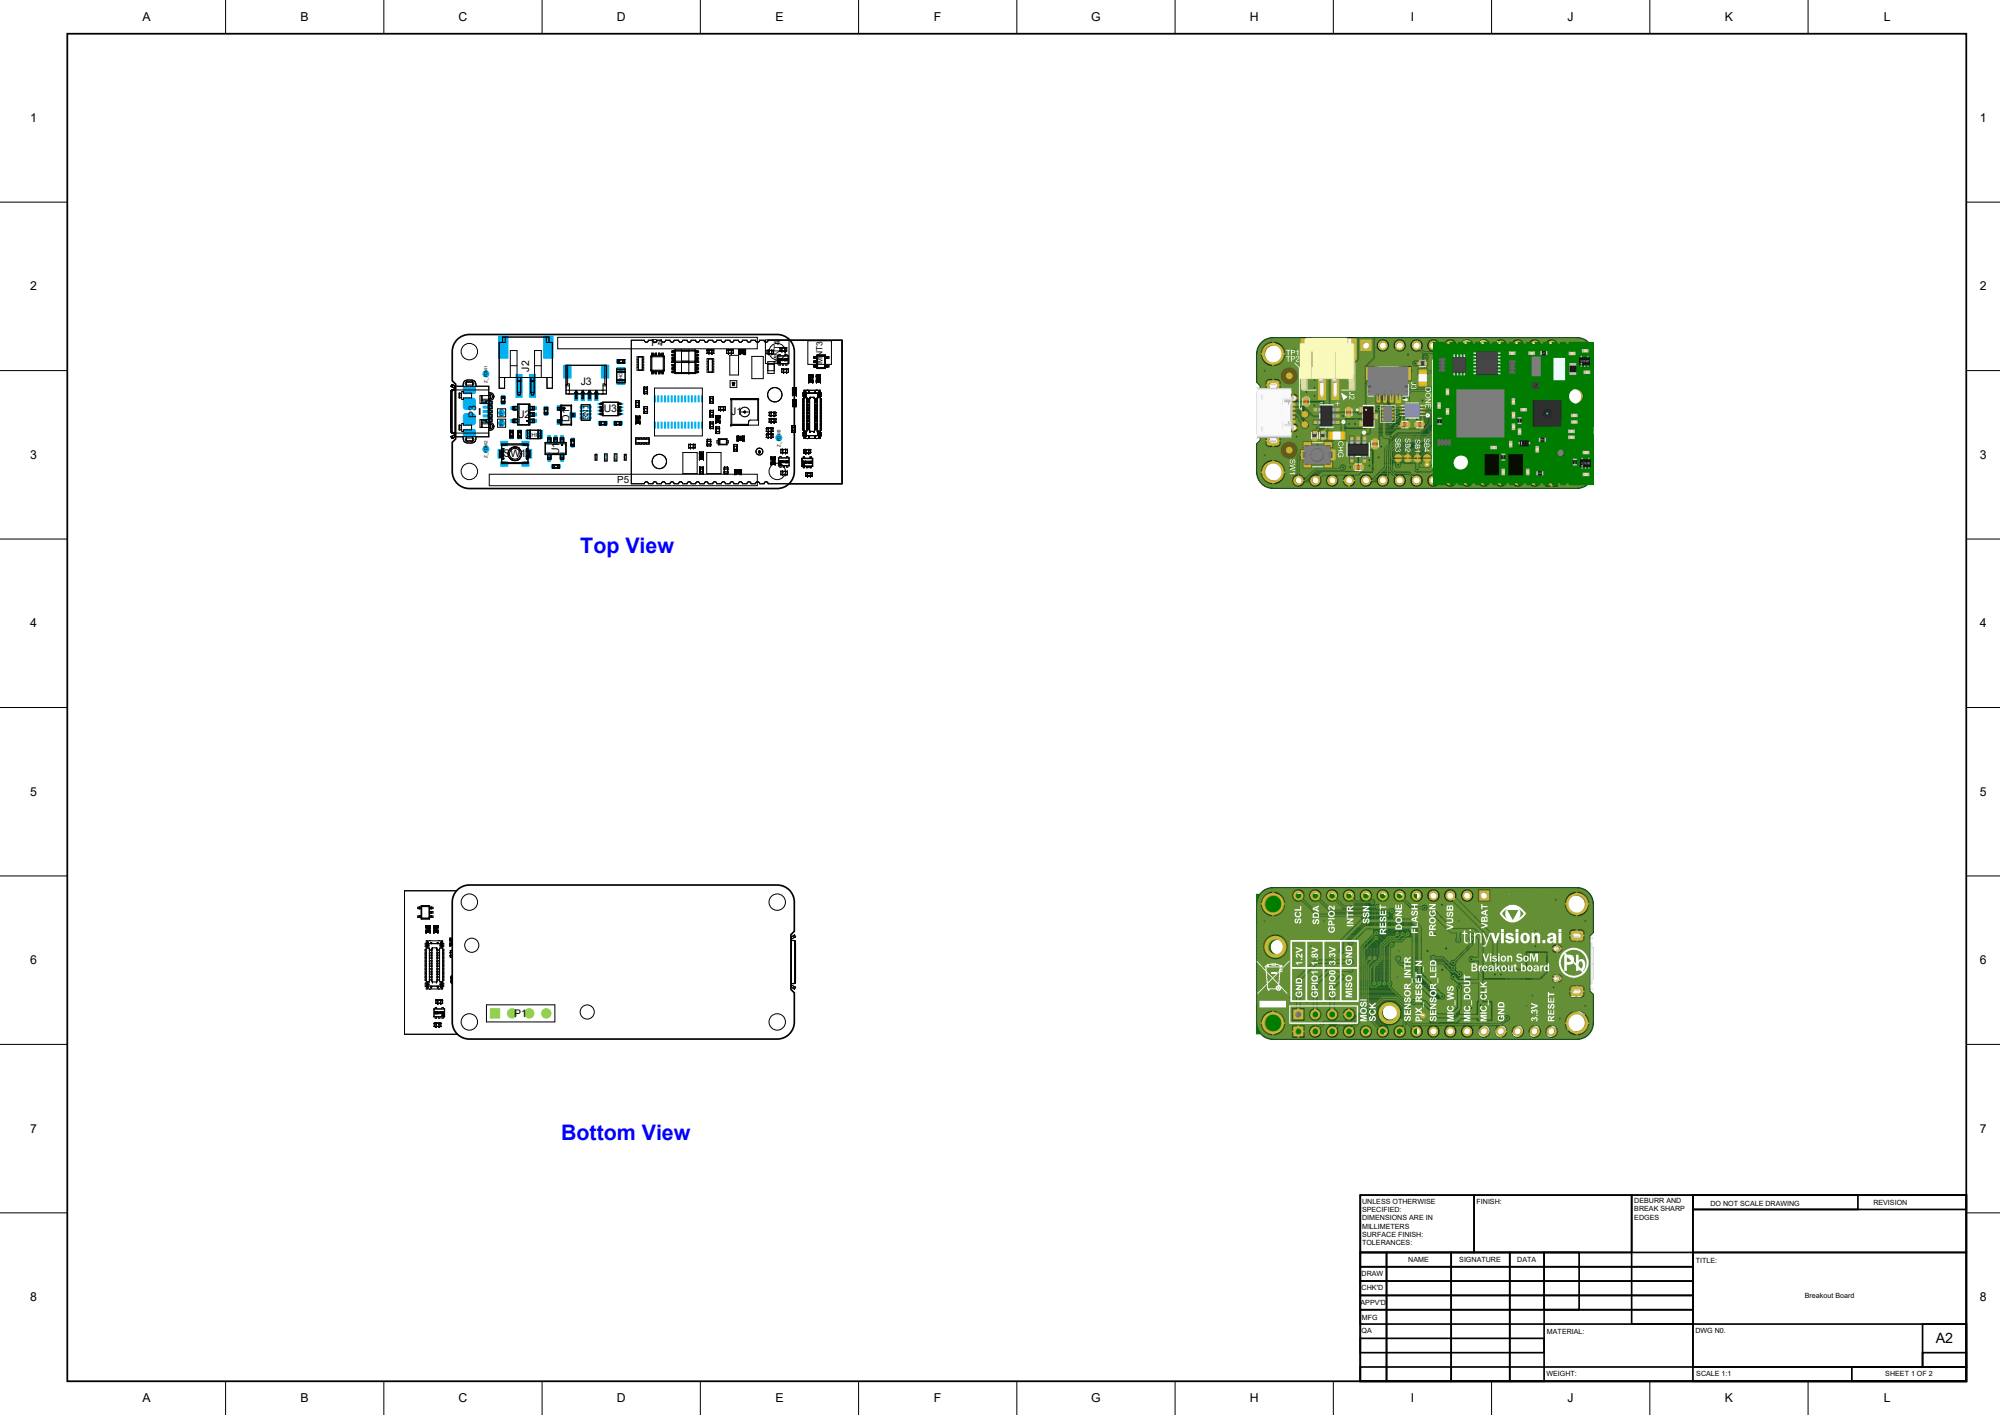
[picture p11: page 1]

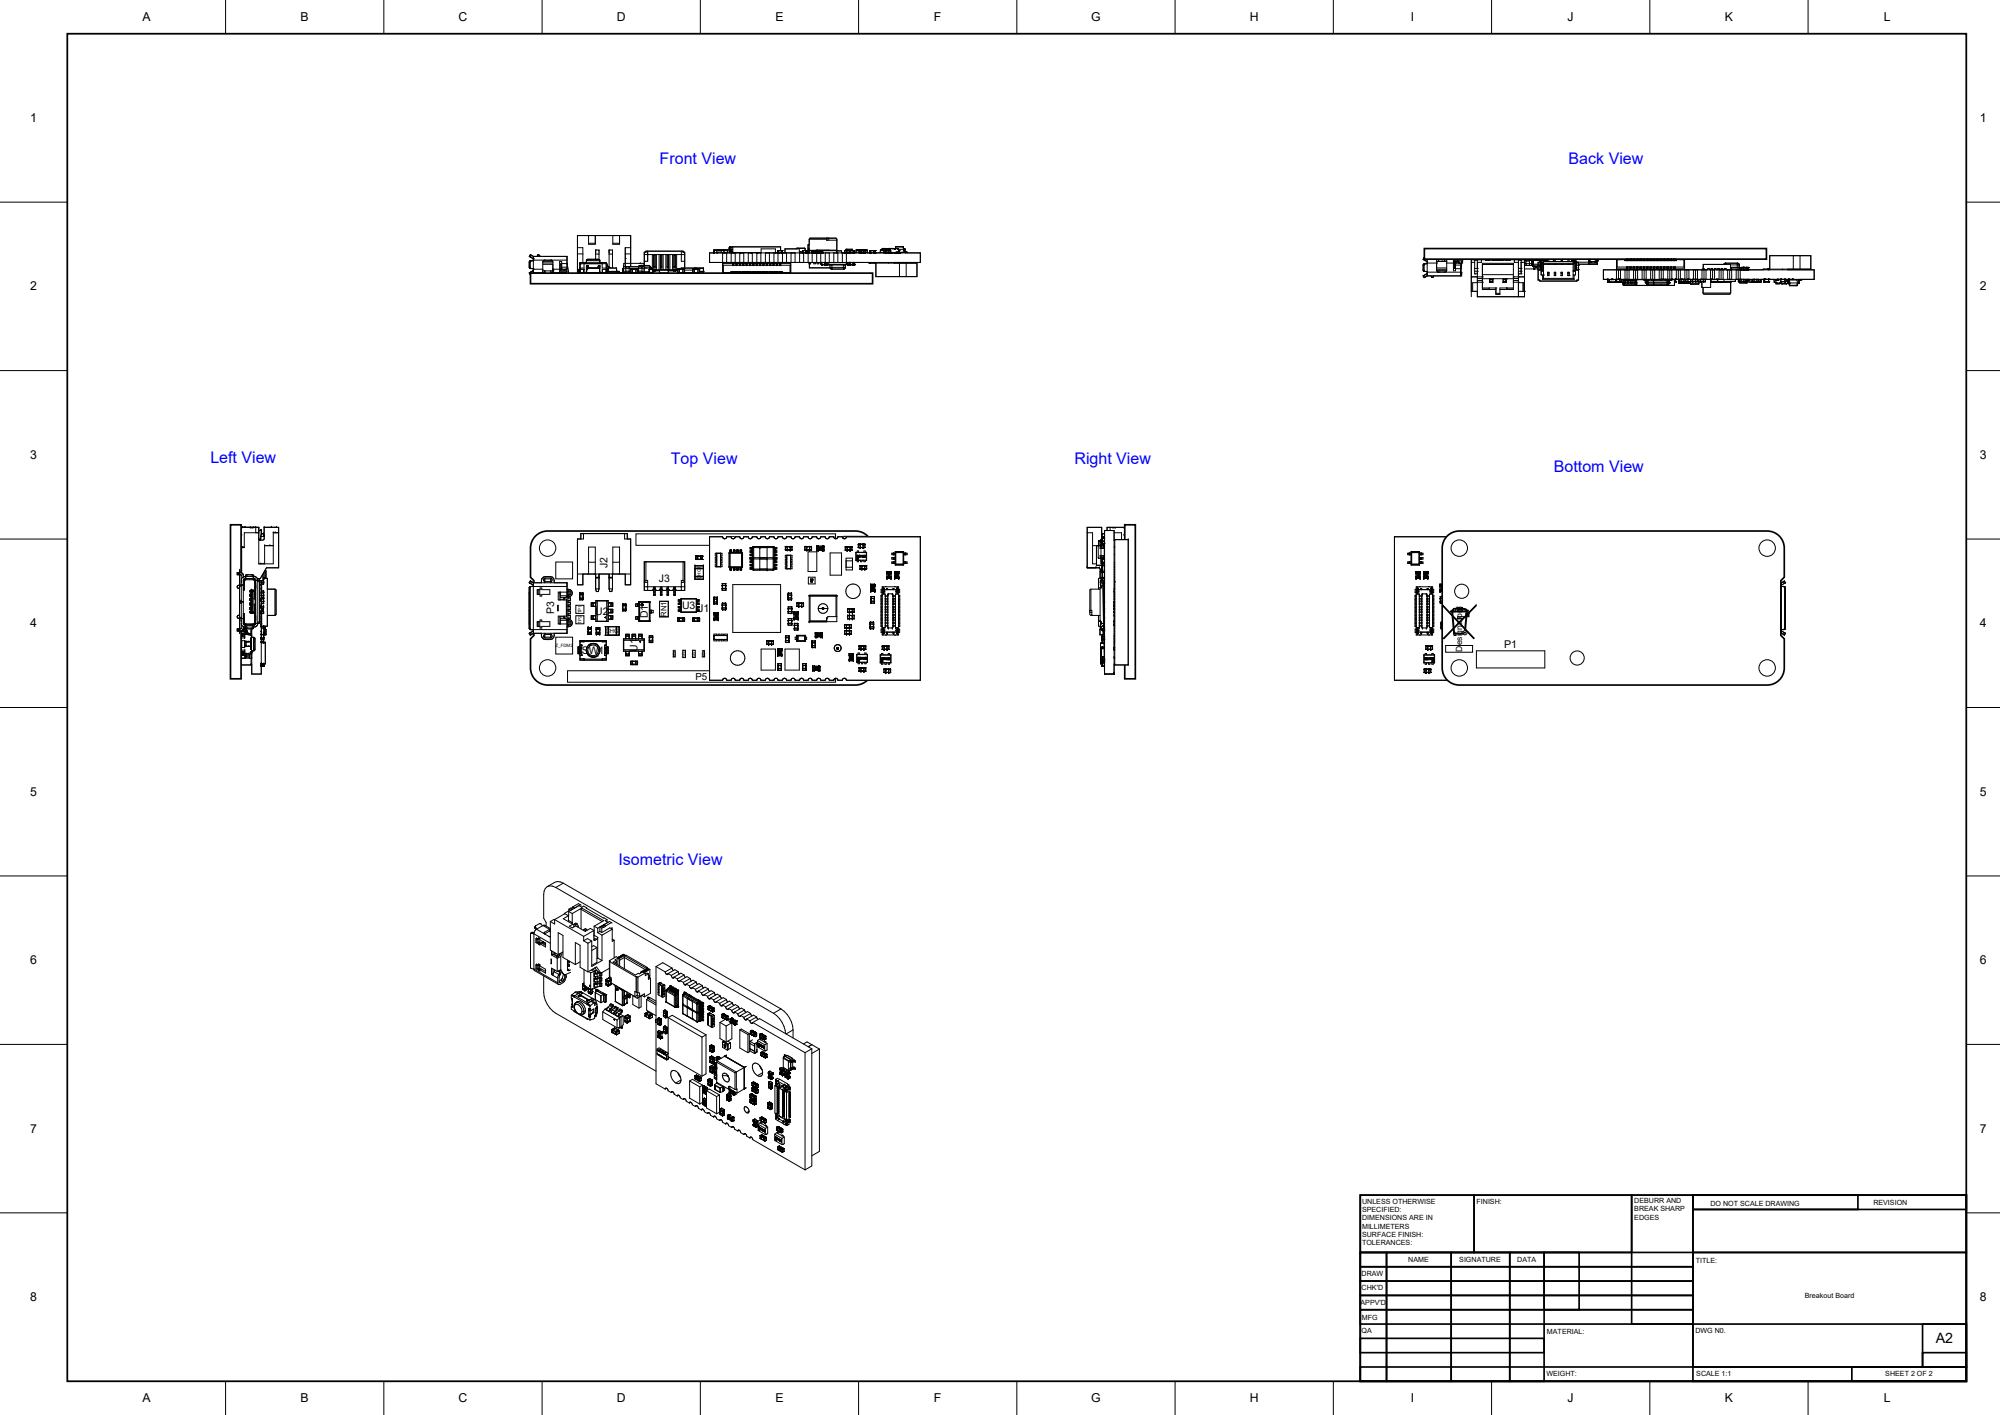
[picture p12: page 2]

NAME | SIGNATURE | DATA | | | | TITLE: Breakout Board

DRAW
CHK'D

APPV'D
MFG
QA | | | | MATERIAL: | DWG N0. | A2

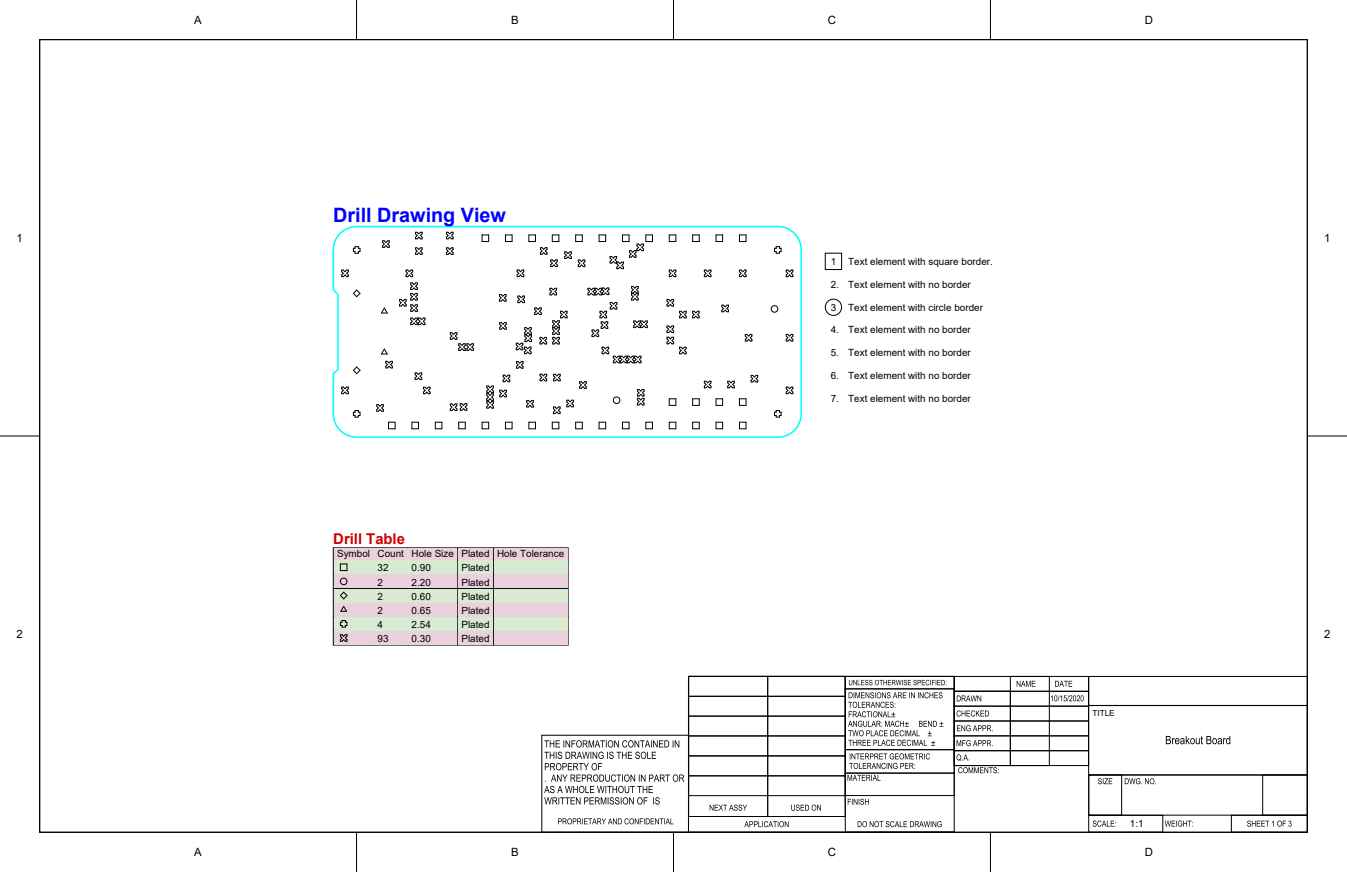
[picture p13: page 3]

2. Text element with no border

3 Text element with circle border

4. Text element with no border

5. Text element with no border

6. Text element with no border

7. Text element with no border

Symbol | Count | Hole Size | Plated | Hole Tolerance

32 | 0.90 | Plated
2 | 2.20 | Plated
2 | 0.60 | Plated
2 | 0.65 | Plated
4 | 2.54 | Plated
93 | 0.30 | Plated

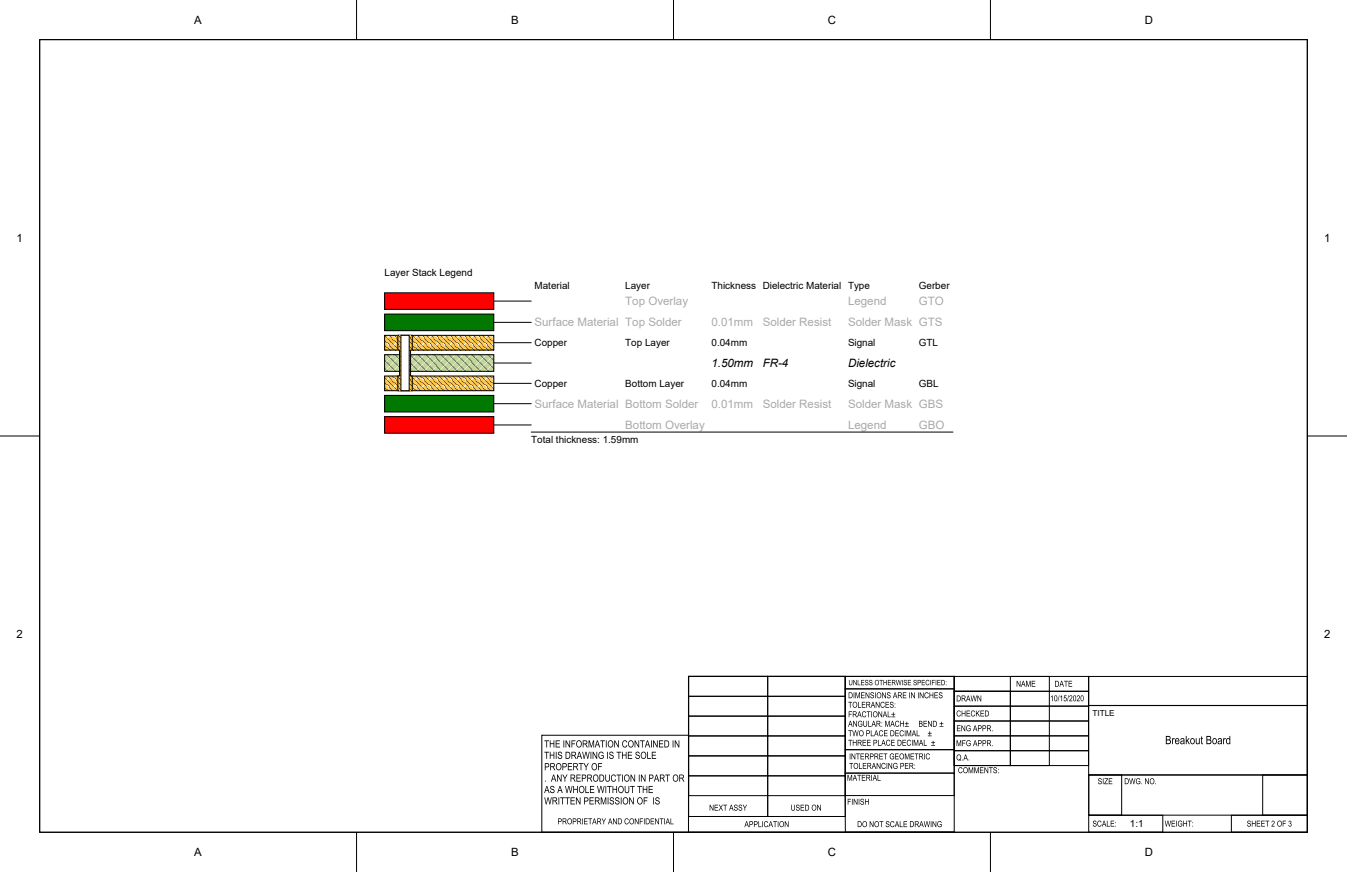
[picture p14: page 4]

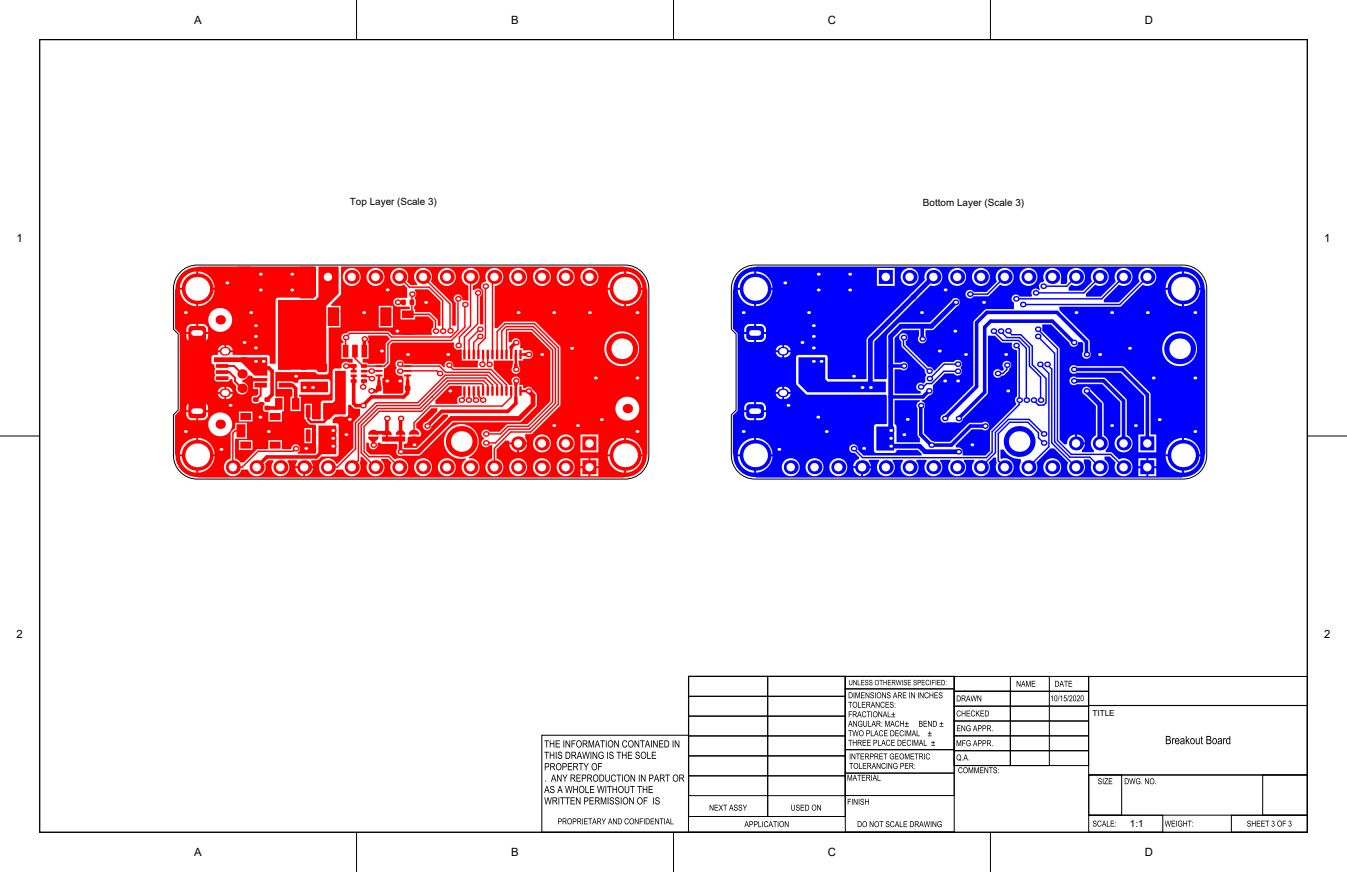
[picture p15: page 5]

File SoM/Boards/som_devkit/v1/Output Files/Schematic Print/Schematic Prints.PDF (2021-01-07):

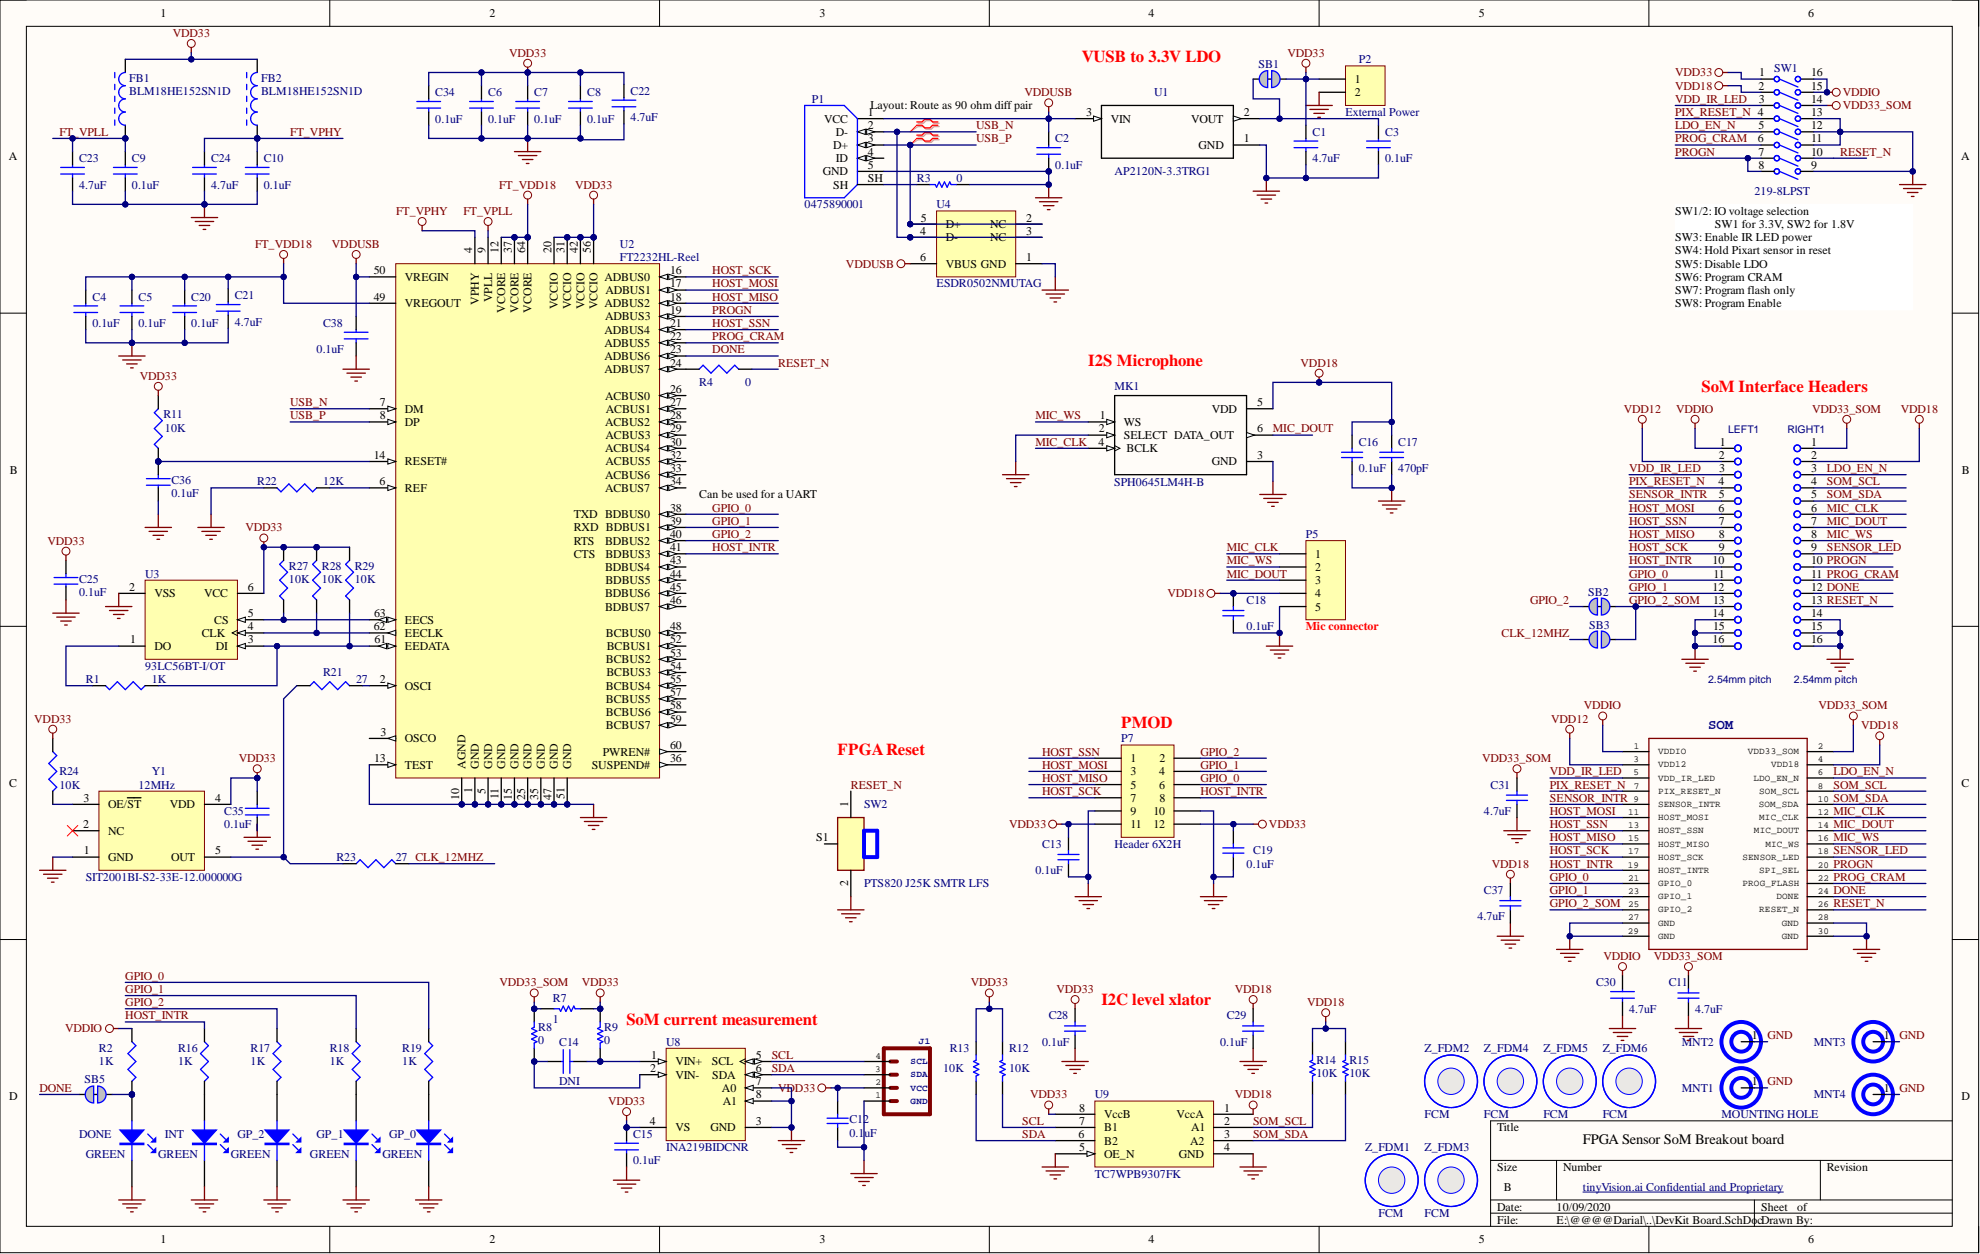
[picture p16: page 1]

Layout: Route as 90 ohm diff pair

USB_N | C2
USB_P

SW3: Enable IR LED power
SW4: Hold Pixart sensor in reset
SW5: Disable LDO
SW6: Program CRAM
SW7: Program flash only
SW8: Program Enable

EECS 63

EEDATA 61

FCM
FPGA Sensor SoM Breakout board

tinyVision.ai Confidential and Proprietary

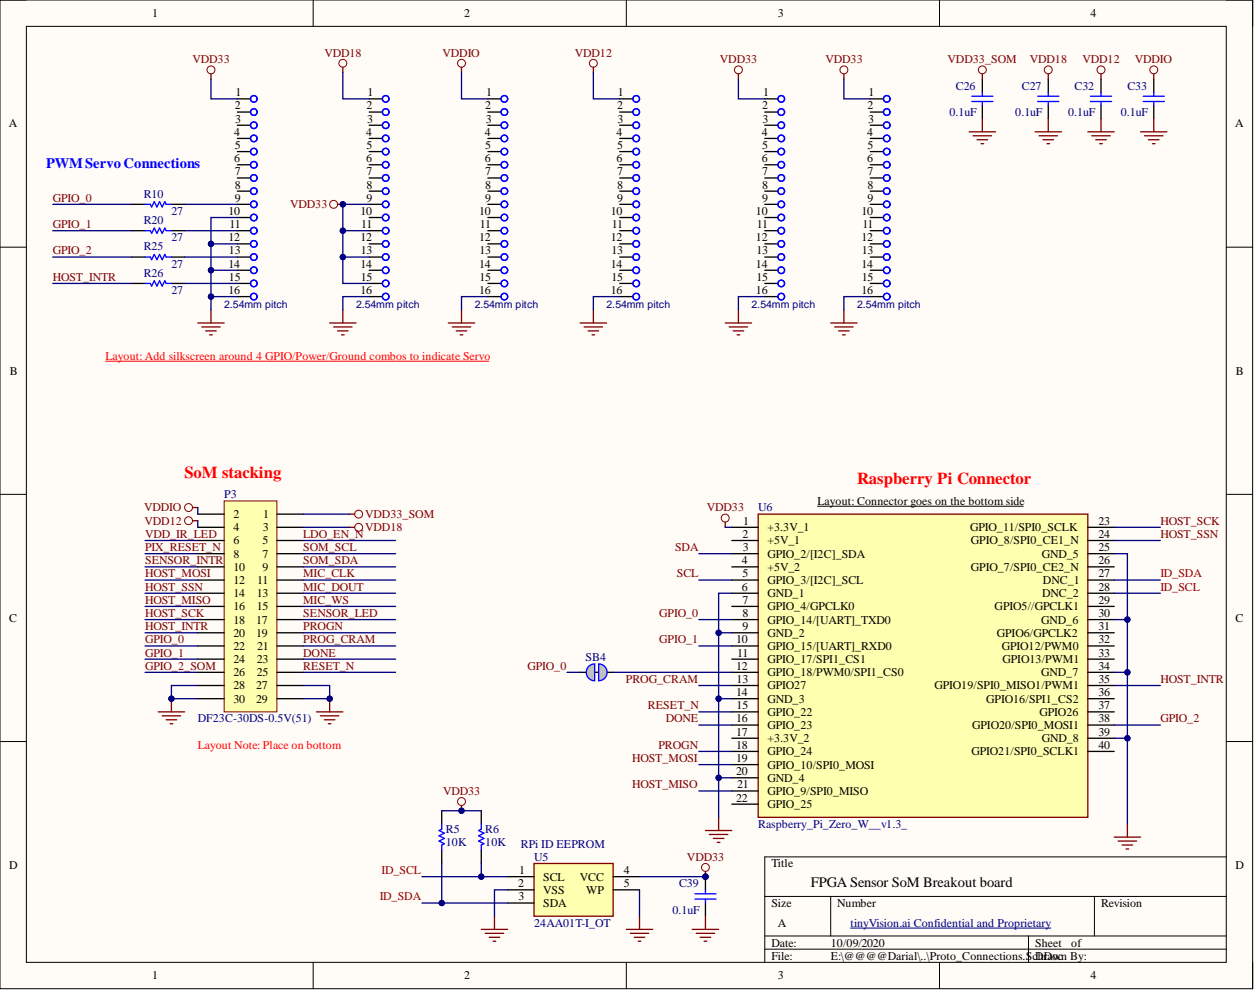
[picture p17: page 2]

Layout: Add silkscreen around 4 GPIO/Power/Ground combos to indicate Servo

Layout: Connector goes on the bottom side

Layout Note: Place on bottom

FPGA Sensor SoM Breakout board

tinyVision.ai Confidential and Proprietary

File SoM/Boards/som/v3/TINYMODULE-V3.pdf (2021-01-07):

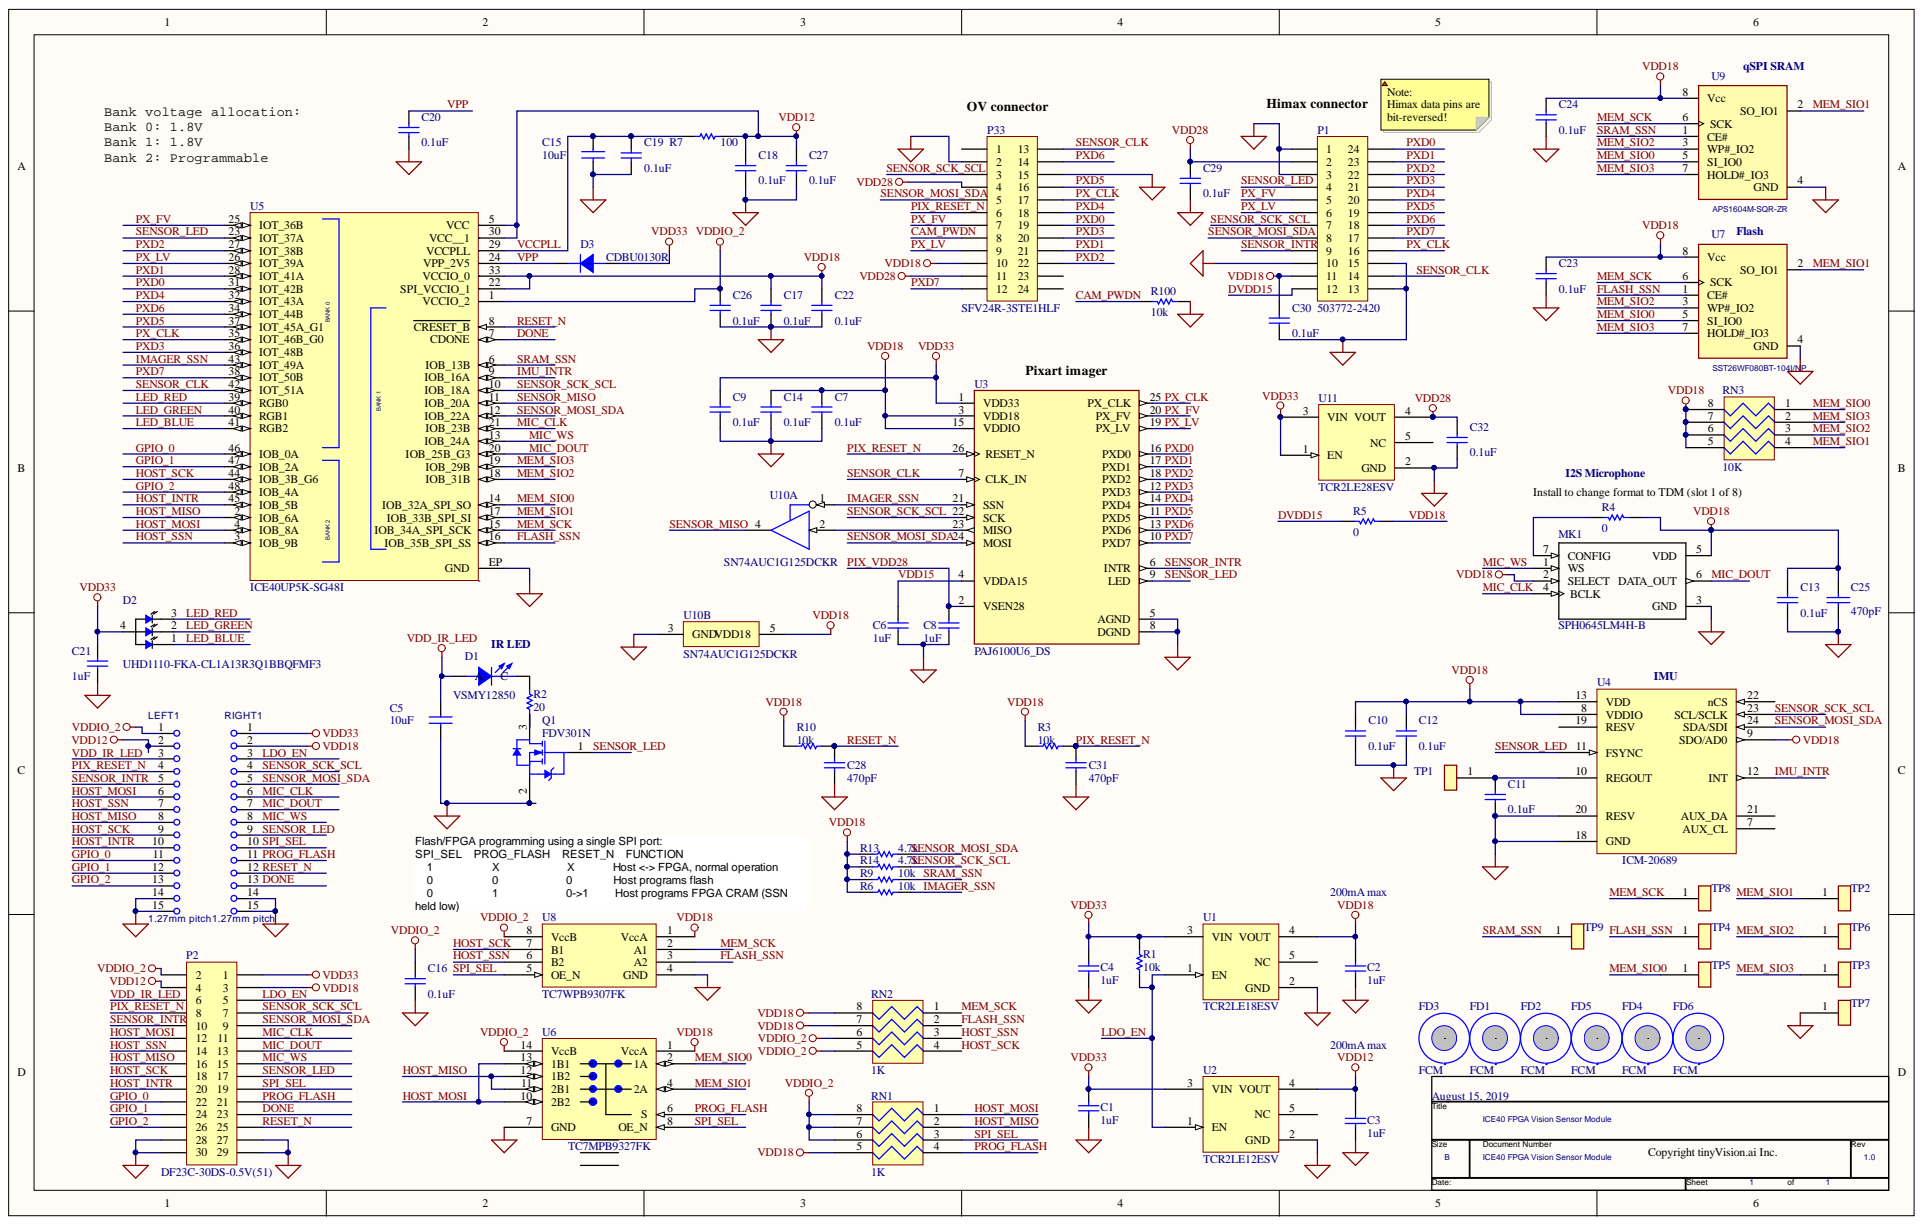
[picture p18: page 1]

Note:
Himax data pins are
bit-reversed!

I2S Microphone
Install to change format to TDM (slot 1 of 8)

Flash/FPGA programming using a single SPI port:
SPI_SEL PROG_FLASH RESET_N FUNCTION
held low)

SPI_SEL | 7 | 2 HOST_MISO

ICE40 FPGA Vision Sensor Module

6 | 3 SPI_SEL

Copyright tinyVision.ai Inc.

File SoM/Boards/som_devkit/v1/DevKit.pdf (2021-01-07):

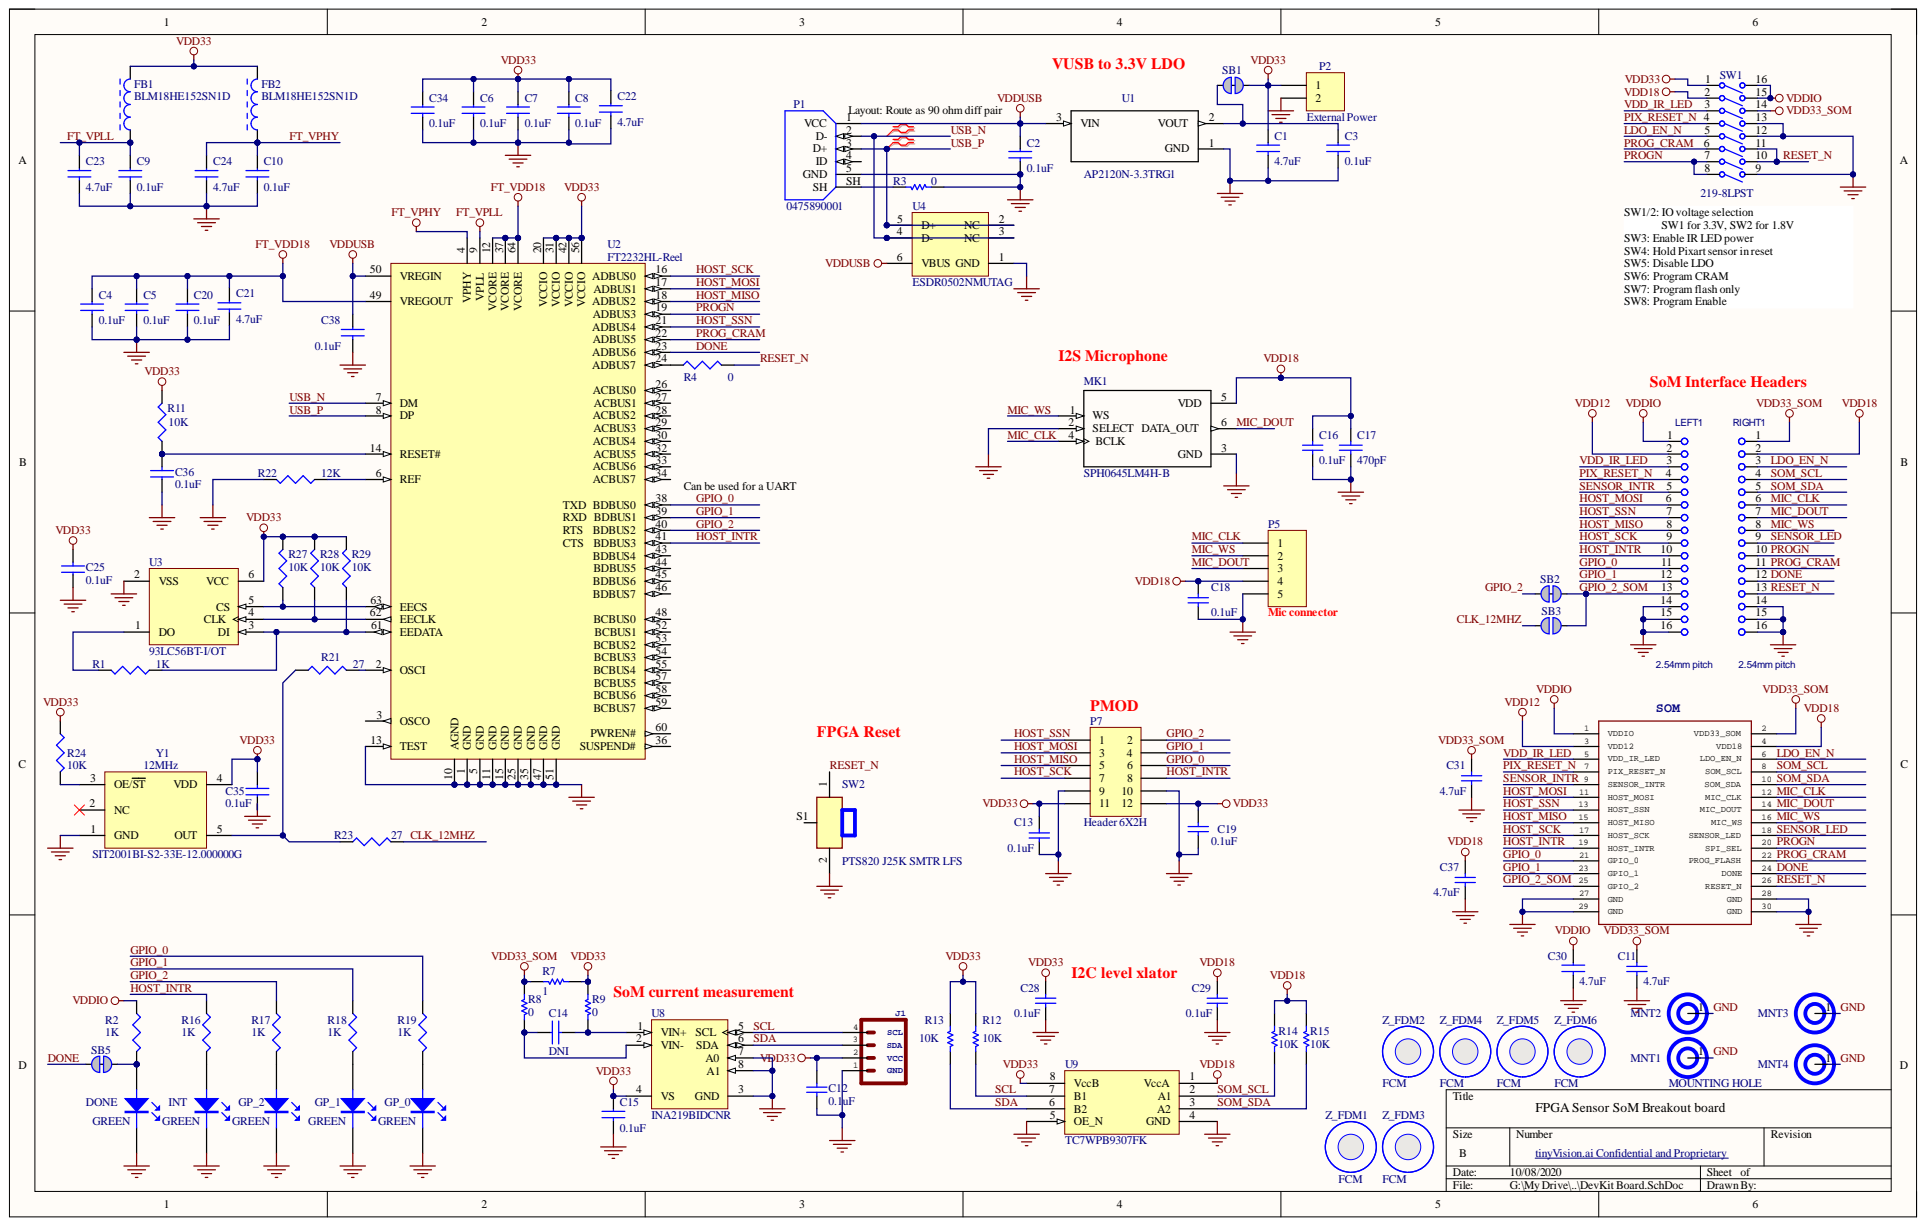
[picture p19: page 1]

Layout: Route as 90 ohm diff pair

SW3: Enable IR LED power
SW4: Hold Pixartsensor in reset
SW5: Disable LDO
SW6: Program CRAM
SW7: Program flash only
SW8: Program Enable

FPGA Sensor SoM Breakout board

Size B | Number tinyVision.ai Confidential and Proprietary | Revision

Date: 10/08/2020 | Sheet of
File: G:\My Drive\..\DevKit Board.SchDoc | DrawnBy:

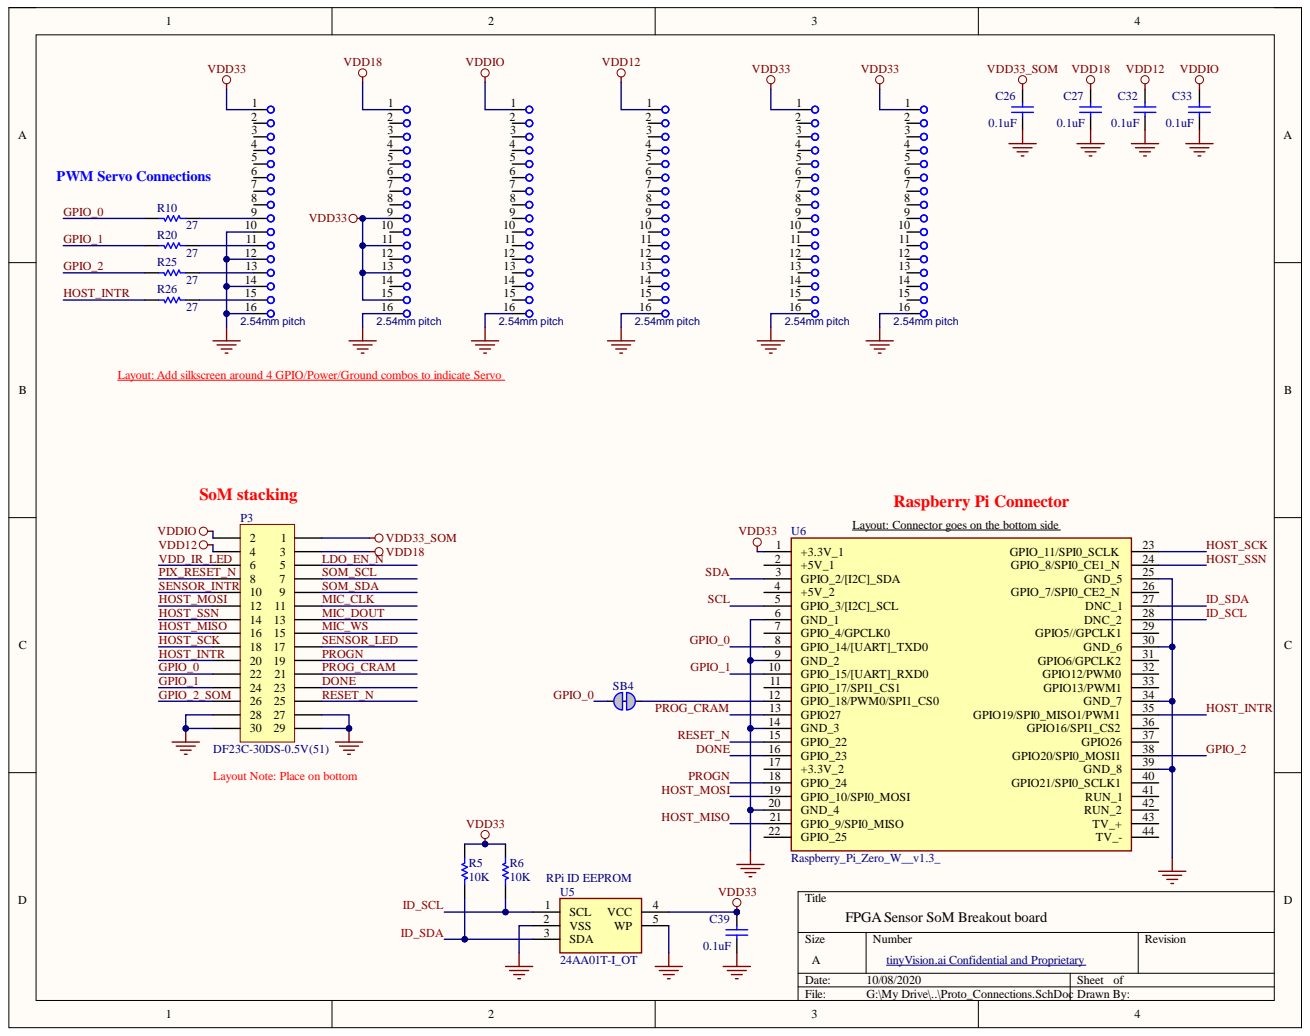
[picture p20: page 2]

Layout: Add silkscreen around 4 GPIO/Power/Ground combos to indicate Servo

Layout: Connector goes on the bottom side

Layout Note: Place on bottom

Title
FPGA Sensor SoM Breakout board

tinyVision.ai Confidential and Proprietary

Item # | Designator | Description | Comment | Quantity | Manufacturer 1 | Manufacturer Part Number 1 | Footprint | LibRef | #Column Name Error:' Note
1 | C1, C11, C21, C22, C23, C24, C30, C31, C37 | 4.7uF, CAP CER 4.7UF 6.3V 0402 | 4.7uF | 9 | | | CAPC1005X60N | CAP NP, Cap_100nF_X7R_10%_040 2
2 | C2, C3, C4, C5, C6, C7, C8, C9, C10, C12, C13, C15, C16, C18, C19, C20, C25, C26, C27, C28, C29, C32, C33, C34, C35, C36, C38, C39 | CAP CER 0.1UF 6.3V 0402, CAP CER 0.1UF 16V Y5V 0402 | 0.1uF | 28 | | | CAPC1005X60N | CAP NP, Cap_100nF_X7R_10%_040 2, Cap_1uF_X5R_10%_6V3_0 402
3 | C14 | CAP CER 0.1UF 6.3V 0402 | DNI | 1 | | | CAPC1005X60N | CAP NP
4 | C17 | CAP CER 470PF 50V 5% NP0 0402 | 470pF | 1 | | | CAPC1005X60N | CAP
5 | DONE, GP_0, GP_1, GP_2, INT | Avago HSMG-C170 | GREEN | 5 | | | LED2012N | LED_1
6 | FB1, FB2 | FERRITE BEAD 1.5 KOHM 0603 1LN | BLM18HE152SN1D | 2 | | | MURA-BLM18-RF-H4-CHIP-2_V | MURA-FB-2
7 | J1 | CONN HEADER SMD R/A 4POS 1MM | | 1 | | | 1X04_1MM_RA | QWIIC_CONNECTORJS-1MM
8 | LEFT1, LEFT2, LEFT3, LEFT4, LEFT5, LEFT6, LEFT7, RIGHT1 | | CONN_GENERIC_1 6 | 8 | | | HDR2x8 | CONN_GENERIC_16
9 | MK1 | Mic Mems Digital I2s Omni -26db | SPH0645LM4H-B | 1 | | | Knowles_SPH0645LM4H-B_0 | SPH0645LM4H-B
10 | MNT1, MNT2, MNT3, MNT4 | | MOUNTING HOLE | 4 | | | MNT620-275N | MNT_1
11 | P1 | CONN RCPT MICRO USB AB 5P SMD RA | 475890001 | 1 | | | *MOLEX_0475890001 | 475890001
12 | P2 | Header, 2-Pin | External Power | 1 | | | HDR1X2 | Header 2
13 | P3 | Header, 15-Pin, Dual row | DF23C-30DS-0.5V(51) | 1 | | | DF23C-30DS-0.5V | Header 15X2
14 | P5 | Header, 5-Pin | Mic connector | 1 | | | HDR1X5 | Header 5
15 | P7 | Header, 6-Pin, Dual row, Right Angle | Header 6X2H | 1 | | | HDR2X6H | Header 6X2H
16 | R1, R2, R16, R17, R18, R19 | RESISTOR 1k OHM 1% 0.0625W 0402 | 1K | 6 | | | RESC1005X40N | R_SH
17 | R3, R8, R9 | RES 0 OHM 1/16W 5% 0402 | 0 | 3 | | | RESC100X50X40L25N | Res_10K_1%_0402
18 | R4 | RESISTOR 0 OHM 1% 0.0625W 0402 | 0 | 1 | | | RESC1005X40N | R_SH
19 | R5, R6, R11, R12, R13, R14, R15, R24, R27, R28, R29 | RES 10K OHM 5% 1/16W 0402, RES SMD 10K OHM 1% 1/16W 0402 | 10K | 11 | | | RESC1005X40N | Res_10K_1%_0402, R_SH
20 | R7 | RES 1 OHM 1/16W 5% 0402 | 1 | 1 | | | RESC1005X40N | Res_10K_1%_0402
21 | R10, R20, R21, R23, R25, R26 | RES 27 OHM 5% 1/16W 0402, RESISTOR 27 OHM 1% 0.0625W 0402 | 27 | 6 | | | RESC1005X40N | Res_10K_1%_0402, R_SH
22 | R22 | RESISTOR 12K OHM 1% 0.0625W 0402 | 12K | 1 | | | RESC1005X40N | R_SH
23 | SOM | Module | Module | 1 | | | SOM-SMD | SOM
24 | SW1 | Switch, SPST, Surface Mount DIP, 8-way, 16-Pin DIP | 219-8LPST | 1 | | | CTS-219-8LPST_V | CTS-219-8LPST-16
25 | SW2 | SWITCH TACTILE SPST-NO 0.05A 12V | PTS820 J25K SMTR LFS | 1 | | | PTS820J25MSMTRLFS | SPST_NO
26 | U1 | IC REG LINEAR 3.3V 150MA SOT23 | AP2120N-3.3TRG1 | 1 | | | *SOT91P240X110-3N | AP2120N-3.3TRG1
27 | U2 | IC USB HS DUAL UART/FIFO 64-LQFP | FT2232HL-Reel | 1 | | | LQFP-64 | COM-UART-FT2232H-LQFP64
28 | U3 | IC EEPROM 2K SPI 2MHZ SOT23-6 | 93LC56BT-I/OT | 1 | | | SOT-23-OT6_L | MEM-SEEPROM-93AA46B-OT-6
29 | U4 | TVS DIODE 5.5V 6UDFN | ESDR0502NMUTAG | 1 | | | ONSC-UDFN-6-517AA-01_V | ONSC-ESDR0502N-UDFN-6-517AA-01
30 | U5 | IC EEPROM 1K I2C 400KHZ SOT23-5 | 24AA01T-I_OT | 1 | | | SOT23-5 | 24AA01T-I_OT
31 | U6 | CONN HDR 40POS 0.1 TIN SMD | Raspberry_Pi_Zero_ W__v1.3_ | 1 | | | RPI0w1.3 | Raspberry_Pi_Zero_W__v1. 3_
32 | U8 | IC CURRENT MONITOR 1% SOT23-8 | INA219BIDCNR | 1 | | | DCN0008A_M | TI-INA219DCN8
33 | U9 | Dual bidirectional level translator | TC7WPB9307FK | 1 | | | SSOP8-P-0.50A | TC7WPB9307FK
34 | Y1 | MEMS OSC XO 12.0000MHZ H/LV-CMOS | 12MHz | 1 | | | SOT23-5 | SIT2001BI-S2-33E
35 | Z_FDM1, Z_FDM2, Z_FDM3, Z_FDM4, Z_FDM5, Z_FDM6 | | FCM | 6 | | | FID100X250N | FCM

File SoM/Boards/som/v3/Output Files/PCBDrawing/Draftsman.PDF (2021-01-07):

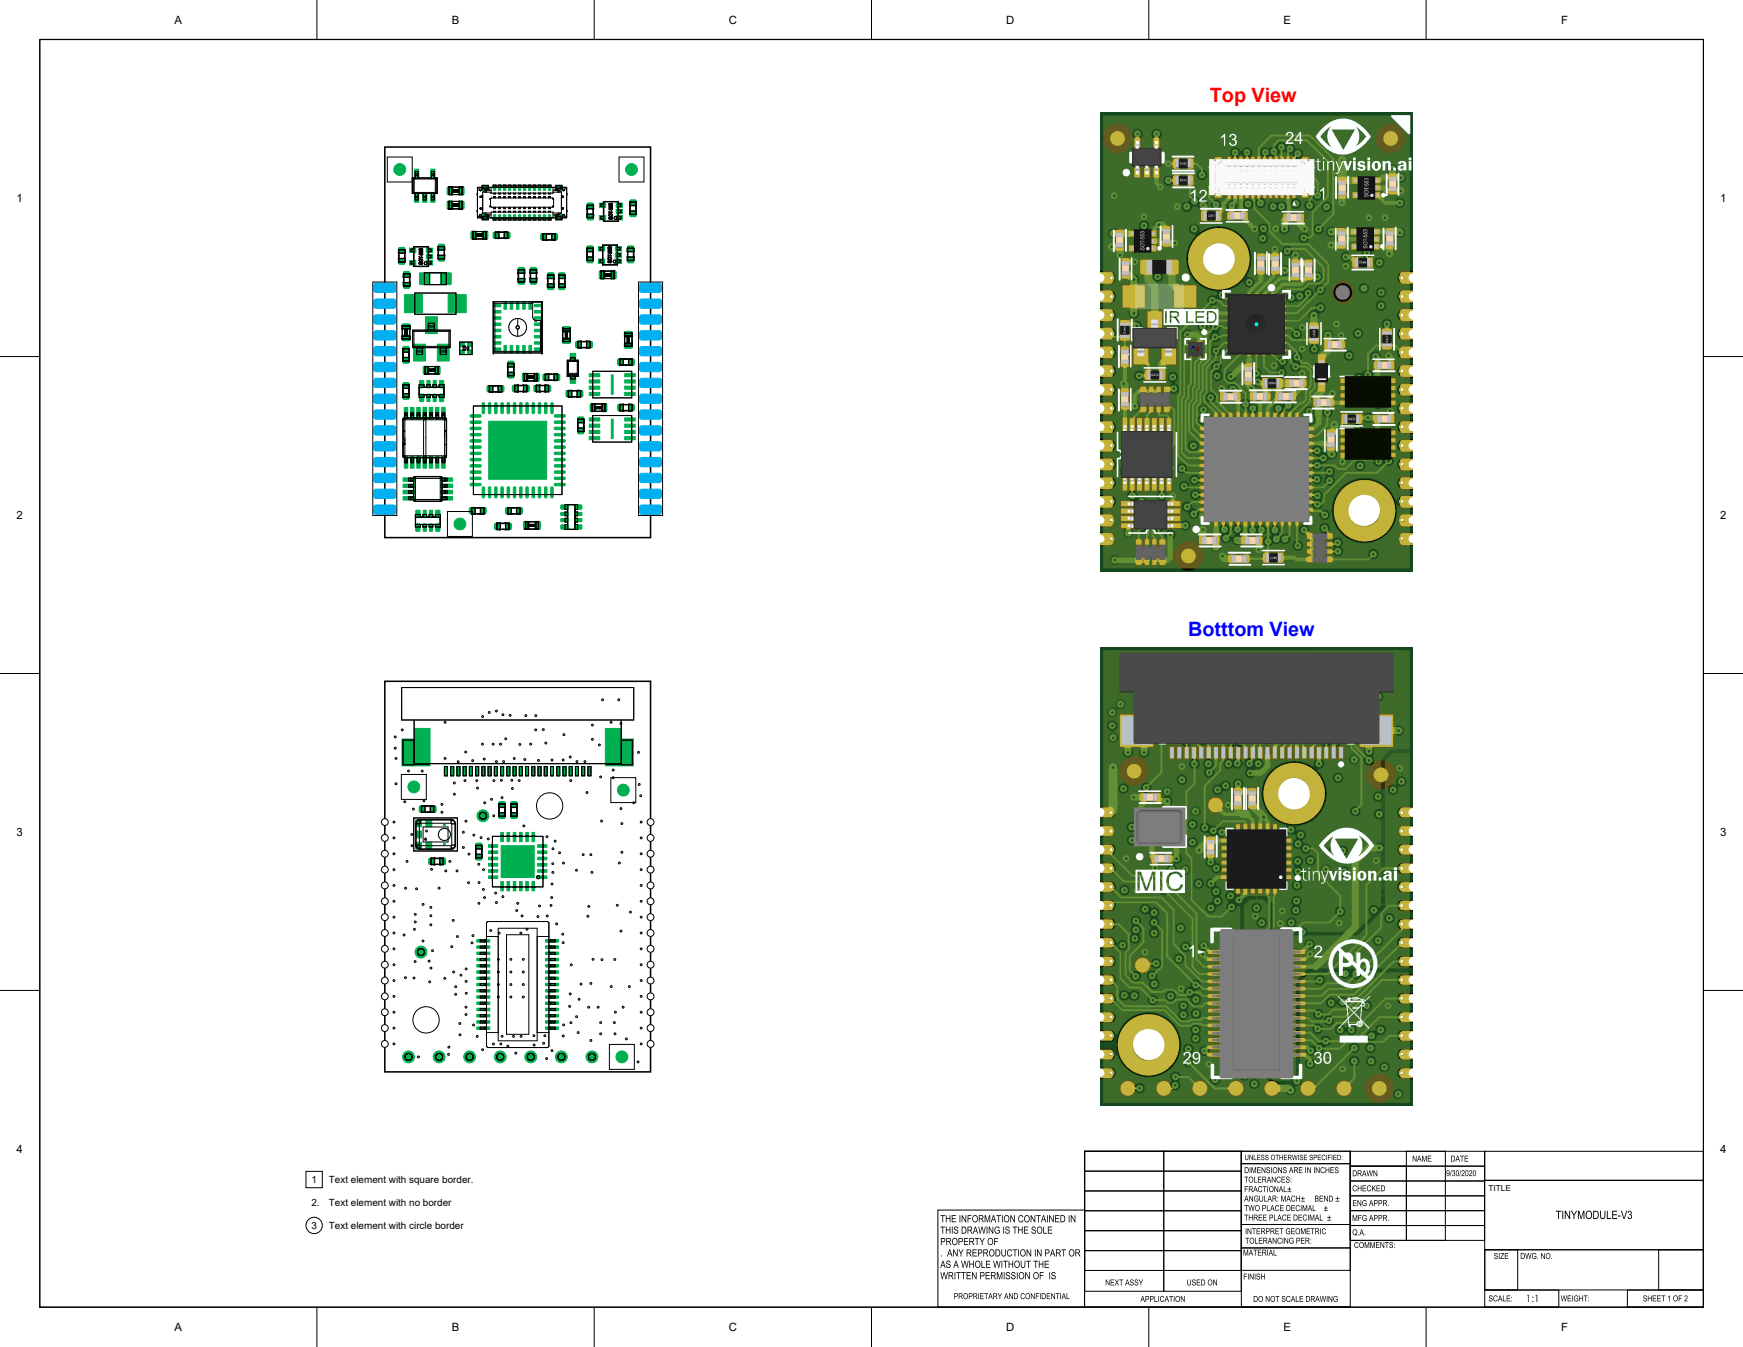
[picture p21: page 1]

2. Text element with no border

3 Text element with circle border


View from Back side (Scale 4:1)


2. Text element with no border

3 Text element with circle border

4. Text element with no border

5. Text element with no border

6. Text element with no border

7. Text element with no border

Symbol | Count | Hole Size | Plated | Hole Tolerance

1 | 1.02 | Non-Plated
30 | 0.60 | Plated
2 | 2.16 | Plated | +/-0.08
232 | 0.20 | Plated | +0.00/-0.20
30 | 0.20 | Plated



CHK'D

APPV'D
MFG
QA | MATERIAL: | DWG N0. | A2

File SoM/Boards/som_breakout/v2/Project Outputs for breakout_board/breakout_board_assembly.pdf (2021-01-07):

A

B


A

B



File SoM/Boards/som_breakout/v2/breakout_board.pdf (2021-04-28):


Si z e | Num b er t inyV i s ion.ai Confident ial and Pr opri et ary | Revi s i on

e : 4/27/ 20 2 1 | Sheet of
Fi l e : G : \My D r ive\..\breakout_board.S chDo c | D rawn By:

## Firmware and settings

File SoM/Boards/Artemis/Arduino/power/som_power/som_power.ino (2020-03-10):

/*
 * Vision SoM Artemis Nano adapter
 * Refer to the drawings at: https://cdn.sparkfun.com/assets/5/5/1/6/3/RedBoard-Artemis-Nano.pdf
 */

// SPI clock is a max of 23MHz when talking to flash and TBD when talking to the FPGA
#define SPI_FREQUENCY 5e6


// SoM control signals
#define SOM_POWER       1
#define SOM_FLASH_SEL   5
#define SOM_PROG_FLASH  3
#define SOM_RESET_N     15
#define SOM_DONE        8

#define SOM_PIX_RESET_N 15
#define SOM_SCK         11
#define SOM_MISO        13
#define SOM_MOSI        12
#define SOM_SSN         4
#define SOM_IRQ         0
#define SOM_GPIO_0      14
#define SOM_GPIO_1      10
#define SOM_GPIO_2      9


// SoM voltages
#define SOM_VDD12        2
#define SOM_VDD18        16

#define LED LED_BUILTIN //Status LED on Artemis carrier boards

#include <Wire.h>

#include <INA219.h>
INA219 monitor;

#include "SPI.h"

#include <pixart.h>
#include <registers.h>
#include <tinyVisionFPGA.h>

#include "test_spi.h"

float vcc;

void setup()
{
  Serial.begin (230400);  
  delay(100);
  Serial.print("tinyVision.ai Inc. Artemis system\n");
  pinMode(LED, OUTPUT);

  analogReadResolution(14); //Set resolution to 14 bit

  //boardBugFix();
  Serial.print("Internal Vcc: ");
  Serial.print(getIntVcc());
  Serial.println("V");

  Serial.print("Internal Temp: ");
  Serial.print(getTemp());
  Serial.println("C");

  powerUp();
  Serial.print("1.2V Vcc: ");
  Serial.print(getCoreVcc());
  Serial.println("V");

  Serial.print("1.8V Vcc: ");
  Serial.print(getIOVcc());
  Serial.println("V");

  TwoWire myWire(3); //Will use pads 42/43
  Wire = myWire;
  Wire.begin();
  Scanner();

  //powerDown();

  monitor.begin();
  // setting up our configuration
  monitor.configure(INA219::RANGE_16V, INA219::GAIN_1_40MV, INA219::ADC_4SAMP, INA219::ADC_4SAMP, INA219::CONT_SH_BUS);
  // calibrate with our values
  monitor.calibrate(1.2, .1, 5, .2);
  monitor.recalibrate();
  Serial.print("Current: ");
  getINA();
  Serial.println("mA");


  // SPI0 is used here, mapped to SPI by the Arduino wrappers
  SPI.begin();

  //test_spi fpga;
  //fpga.testSPI(SPI);

  tvFPGA fpga(SPI_FREQUENCY, SOM_SSN, SOM_IRQ, SOM_RESET_N, SOM_DONE, SOM_FLASH_SEL, SOM_PROG_FLASH);
  digitalWrite(LED, HIGH);

  fpga.reset_fpga();
  fpga.wait_done();
  fpga.init_fpga();

  fpga.read_flash_jedec_id();

}




float getIntVcc(void) {
  int div3 = analogRead(ADC_INTERNAL_VCC_DIV3); //Read VCC across a 1/3 resistor divider
  return (float)div3 * 6 / 16384.0; //Convert 1/3 VCC to VCC
}

float getTemp(void) {
  int volts = analogRead(ADC_INTERNAL_TEMP);
  double internalTemp = volts * 3.3/16384.0; // Assume 3.3V voltage, fix this later
  return (internalTemp/0.0038); //Convert voltage to temp
}

float getCoreVcc(void) {
  int volts = analogRead(SOM_VDD12);
  return (float)volts *2 / 16384.0;
}

float getIOVcc(void) {
  int volts = analogRead(SOM_VDD18);
  return (float)volts *2 / 16384.0;
}

void powerUp(void) {
  pinMode(SOM_POWER, OUTPUT);
  digitalWrite(SOM_POWER, LOW);
  delay(100); // Allow power to settle
}

void powerDown(void) {
  pinMode(SOM_POWER, OUTPUT);
  digitalWrite(SOM_POWER, HIGH);
}

void Scanner ()
{
  Serial.println ();
  Serial.println ("I2C scanner. Scanning ...");
  byte count = 0;

  //wire.begin();
  for (byte i = 8; i < 120; i++)
  {
    Wire.beginTransmission (i);          // Begin I2C transmission Address (i)
    if (Wire.endTransmission () == 0)  // Receive 0 = success (ACK response) 
    {
      Serial.print ("Found address: ");
      Serial.print (i, DEC);
      Serial.print (" (0x");
      Serial.print (i, HEX);     // PCF8574 7 bit address
      Serial.println (")");
      count++;
    }
  }
  Serial.print ("Found ");      
  Serial.print (count, DEC);        // numbers of devices
  Serial.println (" device(s).");
}

void getINA() {
  float shuntVoltage = 0;
  float busvoltage = 0;
  float current_mA = 0;
  float loadvoltage = 0;
  float power_mW = 0;
  /*for (int i=0; i<10; i++) {
    shuntvoltage += monitor.shuntVoltage() * 1000-OFFSET_VOLTAGE;
  }
  shuntvoltage /= 10;
  busvoltage = monitor.busVoltageRaw();
  current_mA = monitor.shuntCurrent() * 1000-OFFSET_CURRENT;
  */
  power_mW = monitor.busPower() * 1000;
  //loadvoltage = monitor.busVoltageRaw();
  //shuntVoltage += monitor.shuntVoltage() * 1000 - OFFSET_VOLTAGE;
/*
  Serial.print("Bus Voltage:   "); Serial.print(busvoltage); Serial.println(" V");
  Serial.print("Shunt Voltage: "); Serial.print(shuntvoltage); Serial.println(" mV");
  Serial.print("Load Voltage:  "); Serial.print(loadvoltage); Serial.println(" V");
  Serial.print("Current:       "); Serial.print(current_mA); Serial.println(" mA");
  Serial.print("Power:         "); Serial.print(power_mW); Serial.println(" mW");
  Serial.println("");
 */
 Serial.println(power_mW);
 //Serial.println(shuntVoltage);
}

void loop()
{
  getINA();
  /*digitalWrite(LED, LOW);
  delay(100);
  digitalWrite(LED, HIGH);
  delay(100);
  */
}

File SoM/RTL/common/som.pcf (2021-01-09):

#set_io creset_n 8
#set_io cdone 7

# Memory (1.8V)
set_io mem_sio[0] 	14
set_io mem_sio[1] 	17
set_io mem_sck 		15
set_io sram_ssn 	6
set_io flash_ssn	16
set_io mem_sio[3] 	19
set_io mem_sio[2] 	18

# Host interface, programmable IO
set_io host_sck_uart_rx 	44
set_io host_mosi_uart_tx 	4

set_io host_sck 	44
set_io host_ssn 	3
set_io host_mosi	4
set_io host_miso 	2
set_io host_intr 	45
set_io gpio[0] 		46
set_io gpio[1] 		47
set_io gpio[2] 		48

# Imager and sensors (1.8V) SPI
set_io sensor_sck 	10
set_io sensor_mosi 	12
set_io sensor_miso 	11
set_io imager_ssn 	35
set_io imu_ssn 		23
set_io imu_intr 	9

# Microphone
set_io mic_clk 		21
set_io mic_ws 		13
set_io mic_dout 	20

# Imager
set_io sensor_clk 	42
set_io px_clk 		43
set_io px_fv 		25
set_io px_lv 		26
set_io pxd[7] 		38
set_io pxd[6] 		34
set_io pxd[5] 		37
set_io pxd[4] 		32
set_io pxd[3] 		36
set_io pxd[2] 		27
set_io pxd[1] 		28
set_io pxd[0] 		31

# On board LED
set_io led_red 		39
set_io led_green 	40
set_io led_blue 	41
set_io sensor_led 	23

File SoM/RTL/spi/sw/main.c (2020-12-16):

#include <stdio.h>
#include "spi_lib.h"

#define SPI_NOP 0x00
#define SPI_INIT 0x01
#define SPI_SEND_BIT_INV 0x02
#define SPI_READ_REQ_BIT_INV 0x03
#define SPI_SET_LED 0x04
#define SPI_READ_REQ_LED 0x05
#define SPI_SEND_VEC 0x06
#define SPI_READ_VEC 0x07

int main()
{
   spi_init();

   uint8_t status, id;

   spi_get_id_status(&id, &status);
   printf("Got ID: 0x%x, Status: 0x%x", id, status);

   return 0;
}

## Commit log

2019-09-04 Added blinking LED code and readme to document it...
2019-09-04 Updated schematics and pictures with annotations
2019-09-05 Updated breakout board schematics
2019-10-14 Added breakout board step file
2019-10-24 Added blink LED code
    Note that this works only with the lattice toolchain and not yosys since the hard macros (LED, PLL) are named differently in the yosys vs. Lattice tools.
2019-12-10 Added power measurements & test code
    [power_himax_10fps.csv, power_himax_no_sensor.csv, power_pixart_2fps.csv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]
2020-03-31 Added SPI slave -> WB master core
2020-04-01 SPI slave core working in sims
2020-10-20 Added servo code, not sure if the timing works out though
2020-10-20 Added a simple camera interface
2020-10-20 Added wishbone camera interface and testbenches
2020-10-28 Initial checkin of SPI slave
    SPI slave implementation: verified initial operation of the block for basic functionality.
2020-12-16 Added SoM tests and SPI update
2021-01-05 Added submodules, IMU testing
2021-01-06 Switched to Modelsim for simulations
2021-01-07 Initial version to build a minimal design with the Himax sensor
2021-01-07 Board design files
    Design files for the 3 boards
    [Assembly Testpoint Report for DevKit - PCB.csv, Assembly Testpoint Report for TINYMODULE-V3.csv, Assembly Testpoint Report for breakout_board.csv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]
2021-01-09 Getting data from the camera, yay!
2021-02-07 Removed references to uart
2021-03-17 Updated to latest SoM CAD files and cleaned up directories
    [Assembly Testpoint Report for TINYMODULE-V3.csv, BOM-TINYMODULE-V3.xlsx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]
2021-03-17 Updated to latest board
    [Assembly Testpoint Report for breakout_board.csv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]
2021-03-17 Added new files for the breakout board
    [Assembly Testpoint Report for DevKit - PCB.csv, Assembly Testpoint Report for breakout_board.csv, BOM-DevKit.xlsx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]
2021-04-28 Removed stray directory for the som breakout board which was wrong
    [Assembly Testpoint Report for breakout_board.csv, Bill of Materials-breakout_board.xlsx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]
2021-04-28 Moving the old breakout board to the v1 directory
    [Assembly Testpoint Report for breakout_board.csv, Bill of Materials-breakout_board.xlsx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]
2021-04-28 Moved files to v1
    [Assembly Testpoint Report for breakout_board.csv, Bill of Materials-breakout_board.xlsx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]
2021-04-28 Added v2 files
    [Assembly Testpoint Report for breakout_board.csv, Bill of Materials-breakout_board.xlsx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]
2021-04-28 Moved v2 to v3
    [Assembly Testpoint Report for TINYMODULE-V3.csv, BOM-TINYMODULE-V3.xlsx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]
2021-04-28 Moved v1 to v2
    [Assembly Testpoint Report for TINYMODULE-V3.csv, BOM-TINYMODULE-V3.xlsx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]
